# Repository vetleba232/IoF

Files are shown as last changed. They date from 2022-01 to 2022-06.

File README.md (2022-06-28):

# Realisation of an ultra-low power LPWAN embedded buoy controller

Altium Designer files for cSLIM-v1, a ultra low-power embedded buoy controller for the Internet of Fish project at NTNU.
The developed PCB design is a part of my specialization project-TTK4551. 

Vetle Berg Abrahamsen, January 2022

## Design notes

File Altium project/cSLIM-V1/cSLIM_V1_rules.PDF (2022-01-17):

## Report Generated From Altium Designer

Name | Priority | Enabled Type | Category | Scope | Attributes
ANT_clearence_polygon | 1 | True | Clearance | Electrical | InNet('nRF_GPS_LN
A') or
InNet('LTE_ANT') or
InNet('NetIC901_11')
orInNet('GPS_ANTE
NNA_nRF') orInNet('
GPS_ANTENNA_EX
T') - All

Generic clearance = 0.125mm, and 6 value(s) for objects

AssemblyTestpoint | 1 | True | Assembly Testpoint
| | | Style | Testpoint | All | Under Comp - Allow Sides - Top, Bottom Pref Size = 1.524mm Pref Hole Size
| | | | | | = 0.813mm Using Grid = Yes Grid = 0.025mm Grid Tolerance = 0mm
AssemblyTestPointUsage | 1 | True | Assembly Testpoint
| | | Usage | Testpoint | All | Testpoint - One Required Multiple - Not Allowed
ComponentClearance | 1 | True | Component Clearance Placement | All - All | Horizontal Clearance = 0.254mm Vertical Clearance = 0.254mm
DiffPairsRouting | 1 | True | Differential Pairs
| | | Routing | Routing | All | Pref Gap = 0.193mm Min Gap = 0.19mm Max Gap = 0.254mmPref Width =
| | | | | | 0.165mm Min Width = 0.165mm Max Width = 0.165mm
FabricationTestpoint | 1 | True | Fabrication Testpoint
| | | Style | Testpoint | All | Under Comp - Allow Sides - Top, Bottom Pref Size = 1.524mm Pref Hole Size
| | | | | | = 0.813mm Using Grid = Yes Grid = 0.025mm Grid Tolerance = 0mm
FabricationTestPointUsage | 1 | True | Fabrication Testpoint
| | | Usage | Testpoint | All | Testpoint - One Required Multiple - Not Allowed
Fanout_BGA | 1 | True | Fanout Control | Routing | IsBGA | Style - Auto Direction - Alternating In and Out Via Grid = 0.025mm
GND_STAR | 1 | False | Routing Topology | Routing | InNet('GND') | Topology - Starburst
Height | 1 | True | Height | Placement | All | Pref Height = 12.7mm Min Height = 0mm Max Height = 25.4mm
HoleSize | 1 | True | Hole Size | Manufacturing | All | Min = 0.2mm Max = 2.54mm
HoleToHoleClearance | 1 | True | Hole To Hole
| | | Clearance | Manufacturing | All - All | Hole To Hole Clearance = 0.279mm
LayerPairs | 1 | True | Layer Pairs | Manufacturing | All | Layer Pairs - Enforce
MinimumAnnularRing | 1 | True | Minimum Annular Ring Manufacturing | All | Min = 0.15mm
MinimumSolderMaskSliver | 1 | True | Minimum Solder Mask
| | | Sliver | Manufacturing | All - All | Minimum Solder Mask Sliver = 0.254mm
NetAntennae | 1 | True | Net Antennae | Manufacturing | All | Net Antennae Tolerance = 0mm
netties rule | 1 | True | Short-Circuit | Electrical | HasFootprint('NETTI
| | | | | E_FP') - All | Short Circuit - Allowed
PasteMaskExpansion | 1 | True | Paste Mask Expansion Mask | All | Expansion = 0mm
PlaneClearance | 1 | True | Power Plane ClearancePlane | All | Clearance = 0.508mm
PlaneConnect | 1 | True | Power Plane Connect
| | | Style | Plane | All | Style - Relief Connect Expansion = 0.508mm Width = 0.254mm Gap =
| | | | | | 0.254mm # Entries = 4
PolygonConnect_1 | 1 | True | Polygon Connect Style Plane | isVia and
| | | | | inNet('GND') or isVia
| | | | | and innet('VDD') orIn
| | | | | Component('IC1201')
| | | | | and InNet('GND') -
| | | | | All | Style - Direct Connect
RoutingCorners | 1 | True | Routing Corners | Routing | All | Style - 45 Degree Min Setback = 2.54mm Max Setback = 2.54mm
RoutingLayers | 1 | True | Routing Layers | Routing | All | TopLayer - Enabled MidLayer1 - DisabledMidLayer2 - Enabled BottomLayer -
| | | | | | Enabled
RoutingPriority | 1 | True | Routing Priority | Routing | All | Priority = 0
RoutingVias | 1 | True | Routing Via Style | Routing | All | Pref Size = 0.5mm Pref Hole Size = 0.25mm
SilkToSilkClearance | 1 | True | Silk To Silk Clearance Manufacturing | All - All | Silk to Silk Clearance = 0.254mm
SilkToSolderMaskClearance | 1 | True | Silk To Solder Mask
| | | Clearance | Manufacturing | IsPad - All | Silk To Solder Mask Clearance = 0.254mm
SMDNeckDown | 1 | True | SMD Neck-Down | SMT | All | Percent = 80%
SolderMaskExpansion_VIA | 1 | True | Solder Mask Expansion Mask | IsVia | Expansion = 0.102mm
UnpouredPolygon | 1 | True | Modified Polygon | Electrical | All | Allow modified - No Allow shelved - No
UnRoutedNet | 1 | True | Un-Routed Net | Electrical | All | (No Attributes)
Width_PWR | 1 | True | Width | Routing | InNetClass('PWR') | Pref Width = 0.4mm Min Width = 0.15mm Max Width = 0.4mm
onsdag 12-jan-12.2022 12:27:38 PM | | | | | | Page 1 of 2

Name | Priority | Enabled Type | Category | Scope | Attributes
Fanout_LCC | 2 | True | Fanout Control | Routing | IsLCC | Style - Auto Direction - Alternating In and Out Via Grid = 0.025mm
PolygonConnect | 2 | True | Polygon Connect Style Plane | All - All | Style - Relief Connect Width = 0.254mm Angle = 90 # Entries = 4 Air Gap =
| | | | | | 0.254mm
RoutingTopology | 2 | True | Routing Topology | Routing | All | Topology - Shortest
ShortCircuit | 2 | True | Short-Circuit | Electrical | All - All | Short Circuit - Not Allowed
SolderMaskExpansion | 2 | True | Solder Mask Expansion Mask | All | Expansion = 0.102mm
USB_polygon | 2 | True | Clearance | Electrical | InNamedPolygon('L1-
| | | | | GND-Polygon') -
| | | | | (IsTrack or IsArc) and
| | | | | (InDifferentialPair('D')
| | | | | orInDifferentialPair('U
| | | | | SB0')) | Clearance = 1.397mm
Width_diff | 2 | True | Width | Routing | (InDifferentialPairClas
| | | | | s('All Differential
| | | | | Pairs')) | Pref Width = 0.165mm Min Width = 0.165mm Max Width = 0.165mm
Fanout_SOIC | 3 | True | Fanout Control | Routing | IsSOIC | Style - Auto Direction - Alternating In and Out Via Grid = 0.025mm
USB_clearence | 3 | True | Clearance | Electrical | (InDifferentialPairClas
| | | | | s('All Differential
| | | | | Pairs')) - All | Generic clearance = 0.152mm, and 9 value(s) for objects
Width_GPIO_1 | 3 | True | Width | Routing | InNetClass('GPIO') or
| | | | | InNetClass('COEX')
| | | | | or InNetClass('SWD')
| | | | | or
| | | | | InNetClass('UART') | Pref Width = 0.15mm Min Width = 0.15mm Max Width = 0.152mm
Fanout_Small | 4 | True | Fanout Control | Routing | (CompPinCount < 5) Style - Auto Direction - Out Then In Via Grid = 0.025mm
nRFfootprint | 4 | True | Clearance | Electrical | HasFootprint('XCVR_
| | | | | NRF9160-SICA-R7')
- All
| | | | | | Clearance = 0.125mm
Width | 4 | True | Width | Routing | All | Pref Width = 0.15mm Min Width = 0.15mm Max Width = 0.254mm
Fanout_Default | 5 | True | Fanout Control | Routing | All | Style - Auto Direction - Alternating In and Out Via Grid = 0.025mm
Polygon_Clearence | 5 | True | Clearance | Electrical | (InNamedPolygon('L1
| | | | | -GND-Polygon')) or(In
| | | | | NamedPolygon('L4-G
| | | | | ND-Polygon')) or(InN
| | | | | amedPolygon('L2-GN
| | | | | D_polygon')) or(InNa
| | | | | medPolygon('L3-GND
| | | | | -Polygon')) - All | Generic clearance = 0.254mm, and 9 value(s) for objects
Top_layer_Clearance | 6 | True | Clearance | Electrical | All - OnLayer('Top Layer') | Clearance = 0.125mm
Clearance | 7 | True | Clearance | Electrical | All - All | Clearance = 0.125mm
onsdag 12-jan-12.2022 12:27:38 PM | Page 2 of 2

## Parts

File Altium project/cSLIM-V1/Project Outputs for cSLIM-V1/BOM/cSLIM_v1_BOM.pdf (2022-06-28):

Designator | Value | Quantity | Manufacturer_Part_Number | Description
A1 | | 1 | P822601 | CDMA, DCS, EDGE, GPRS, GSM, HSDPA, LTE, PCS, UMTS, WCDMA Flat Bar RF Antenna
C301, C401, C402, C403, C404, C405, C601, C604, C606, C806, C810, C901, C904, C905, C907, C1001, C1202, C1205, C1209, C1215 | 100nF | 20 | CL10B104KB8NNNL | Capacitor
C501 | 12pF | 1 | 0603N120J500CT | Capacitor
C502 | 10nF | 1 | CL10B103KB8NNNC | Capacitor
C602, C603, C902, C1216, C1217 | 1uF | 5 | CL10A105KO8NNNC | Capacitor
C605 | 10uF | 1 | CL10X106MP8NRNC | Capacitor
C607 | 22uF | 1 | CL10A226KQ8NRNE | Capacitor
C608 | 1.8pF | 1 | CL10C1R8BB8NNNC | Capacitor
C609 | | 1 | PCH1E101MCL4GS | Alum.Organic Polymer Capacitors 100UF 25V ESR=27
C807 | 1uF/50V | 1 | CL10A105KB8NNNC | Capacitor
C903, C906 | 100pF | 2 | CL10C101JB8NNNC | Capacitor
C1201, C1208 | 15pF | 2 | CL10C150JB81PNC | Capacitor
C1203, C1210 | 47uF | 2 | GRM188D70E476ME01D | Capacitor
C1206, C1207 | 4.7uF | 2 | CL10A475KQ8NNNC | Capacitor
C1211 | 3.5pF | 1 | CL10C3R3CB81PNC | Capacitor
C1212, C1213, C1214 | N.C. | 3 | | Capacitor
D601 | | 1 | 1SS390SMFHT2R | RF Diode PIN - Single 35V 100 mA EMD2
D1201 | | 1 | CM1402-03CP | FILTER RC(PI) ESD SMD
FB501 | 500 mA, 600 Ohms | 1 | BLM18EG601SZ1D | Ferrite bead
FB801, FB802 | 60 OHM | 2 | 742792602 | Ferrite bead, [NoValue]
FB1201 | 120ohm 0.7A | 1 | BLM18AG121SH1D | Ferrite bead - 120ohm 0.7A
IC201 | | 1 | WLR089U0-I/RM | LONG RANGE LORA MODULE (863-928
IC202, IC701, IC902 | | 3 | SN74AVC4T774PWR | Logic Level Converter (LLC)
IC203, IC702, IC903 | | 3 | NX2301P,215 | P-Channel 20V 2A (Ta) 400mW (Ta), 2.8W (Tc) Surface Mount TO-236AB
IC301 | | 1 | MAX3486ESA+ | 1/1 Transceiver Half RS422, RS485 8-SOIC
IC302 | | 1 | MAX3471EUA+ | 1/1 Transceiver Half RS485 8-uMAX-EP|8-uSOP-EP
IC401 | | 1 | MAX3221CUE+ | 1/1 Transceiver Full RS232 16-TSSOP
IC601 | | 1 | TPS2113PWR | OR Controller Source Selector Switch N-Channel 2:1
IC901 | | 1 | NEO-M8N-0-10 | NEO-M9N-00B should be used if available
IC904 | | 1 | SKY65943-11 | GPS LNA MODULE
IC1001 | | 1 | CY15B108QN-20LPXC | IC FRAM 8MBIT SPI 20MHZ 8GQFN
IC1201 | | 1 | NRF9160-SICA-B1A-R7 | IC RF TxRx + MCU Cellular GPS 700MHz ~ 2.2GHz 161-TFLGA Module
IC1202 | | 1 | PCAL6408APWJ | I/O Expander 8 I2C, SMBus 400 kHz 16-TSSOP
J301, J302 | | 2 | 61300211121 | CONN HEADER VERT 2POS 2.54MM
J501 | | 1 | 70543-0001 | BAT CONN HEADER VERT 2POS 2.54MM
J502 | | 1 | PH1-04-UA | CONN HEADER VERT 4POS 2.54MM
J503 | | 1 | 61300611121 | CONN HEADER VERT 6POS 2.54MM
J504 | | 1 | 10119313-302TLF | USB - mini B USB 2.0 Receptacle Connector 5 Position Through Hole
J505, J515 | | 2 | 61300311121 | CONN HEADER VERT 3POS 2.54MM
J506 | | 1 | 104031-0811 | CONN MICRO SD CARD PUSH-PULL R/A
J507, J514 | | 2 | CONUFL001-SMD-T | CONN UMC JACK STR SMD
J508, J512 | | 2 | SHF-105-01-L-D-SM-LC-K-TR | CONN HEADER SMD 10POS 1.27MM
J509, J510 | | 2 | BM05B-ZESS-TBT (LF)(SN) | RS232/RS485 CONN HEADER SMD 5POS 1.5MM
J513 | | 1 | SF72S006VBAR2500 | NANO SIM CARD PUSH-PUSH
J516 | | 1 | TSW-103-08-S-D | Auxillary 2x3 conn
J802 | | 1 | 52746-1071 | LCD connector CONN FFC BOTTOM 10POS 0.50MM R/A
L601 | | 1 | LPS3015-222MRB | Inductor
L901 | 27nH | 1 | LQG18HH27NJ00D | Inductor
L902 | 9n1 | 1 | LQW18AN9N1D00D | Inductor
L1201 | 22nH | 1 | LQW18AN22NJ00D | Inductor
L1202 | 1.5nH | 1 | LQG18HN1N5S00D | Inductor
LED501 | | 1 | APT2012LSECK/J3-PRV | LED RED CLEAR 2SMD
LED502 | | 1 | APT2012LSYCK/J3-PRV | LED YELLOW CLEAR 2SMD
LED503 | | 1 | APT2012LZGCK | LED GREEN CLEAR 2SMD
LED504, LED505 | | 2 | APT2012LVBC/D | LED BLUE CLEAR 2SMD
PB1201, PB1202, S601 | | 3 | TLS A 070J LFS | SWITCH TACTILE SPST-NO 0.05A 12V
Q901 | | 1 | SI1040X-T1-GE3 | IC PWR SWITCH P-CHAN 1:1 SC89-6
R201, R202, R203, R603, R701, R702, R703, R801, R804, R901, R902, R903, R906, R1102, R1103, R1209, R1210, R1211, R1212, R1213 | 100k | 20 | RC0603FR-07100KL | Resistor
R301 | 120R | 1 | RT0603DRD07120RL | Resistor
R302, R303 | 680R | 2 | RC0603JR-07680RL | Resistor
R501, R502 | 15R | 2 | RC0603JR-0715RL | Resistor
R503, R508, R509, R511, R904, R907, R908, R1204, R1205, R1206, R1216, R1217 | 0R | 12 | YJP1608-R001 | Resistor
R504, R505 | 820R | 2 | RC0603FR-07820RL | Resistor
R506, R507, R510 | 330R | 3 | RC0603FR-07330RL | Resistor
R601, R609 | 240k | 2 | RC0603FR-07240KL | Resistor
R602, R606, R909 | 1M | 3 | RC0603FR-131ML | Resistor
R604 | 390R | 1 | RC0603JR-07390RL | Resistor
R605, R1214, R1215 | 1k | 3 | RC0603FR-071KL | Resistor
R607 | 100R | 1 | RC0603FR-07100RL | Resistor
R608 | 1M2 | 1 | RC0603FR-071M2L | Resistor
R610 | 3k | 1 | RC0603FR-073KL | Resistor
R905 | 10R | 1 | RC0603FR-1310RL | Resistor
R1001, R1002 | 33R | 2 | RC0603FR-0733RL | Resistor
R1003 | 50R | 1 | RC0603FR-0749R9L | Resistor
R1101, R1201 | 10k | 2 | RC0603FR-0710KL | Resistor
R1202, R1203 | 4.7k | 2 | RC0603FR-074K7L | Resistor
S201 | | 1 | 97C08ST | 8-Pin address switch
U501 | | 1 | USBLC6-2SC6 | 17V Clamp 5A (8/20µs) Ipp Tvs Diode SMD
U601 | | 1 | TPS63000DRCR | Buck-Boost Switching Regulator IC Positive Adjustable 1.2V 1 Output 1.6A (Switch) 10-VFDFN Exposed Pad
Y1101 | | 1 | RV-3032-C7-TA-QC | Real Time Clock Serial I2C 16Bytes 8-Pin SON T/R
Display | 1 | LS013B7DH03 | LCD TFT 1.28" 128X128 FPC
Jumper | 3 | SPC02SXIN-RC | CONN JUMPER SHORTING .100" GOLD
GNSS antenna | 1 (2) | FXP611.07.0092C | RF ANT 1.6GHZ FLAT PATCH IPEX. (Internal or external)
cSLIM-v1 PCB + stencil | 1 | W485774ASF10 | Prod.num can be used to repeat order: stock 9 PCB
SWD cable | 1 | 1528-2009-ND | 10-PIN 2X5 SOCKET-SOCKET 1.27MM
USB cable | 1 | Not specified | USB 2.0 to USB MINI for power.
SEGGER programmer | 1 | Not specified | SWD prog and RTT view. SEGGER EDU or nRF9160 DK.

Components not specified in the generated BOM

Required accessories

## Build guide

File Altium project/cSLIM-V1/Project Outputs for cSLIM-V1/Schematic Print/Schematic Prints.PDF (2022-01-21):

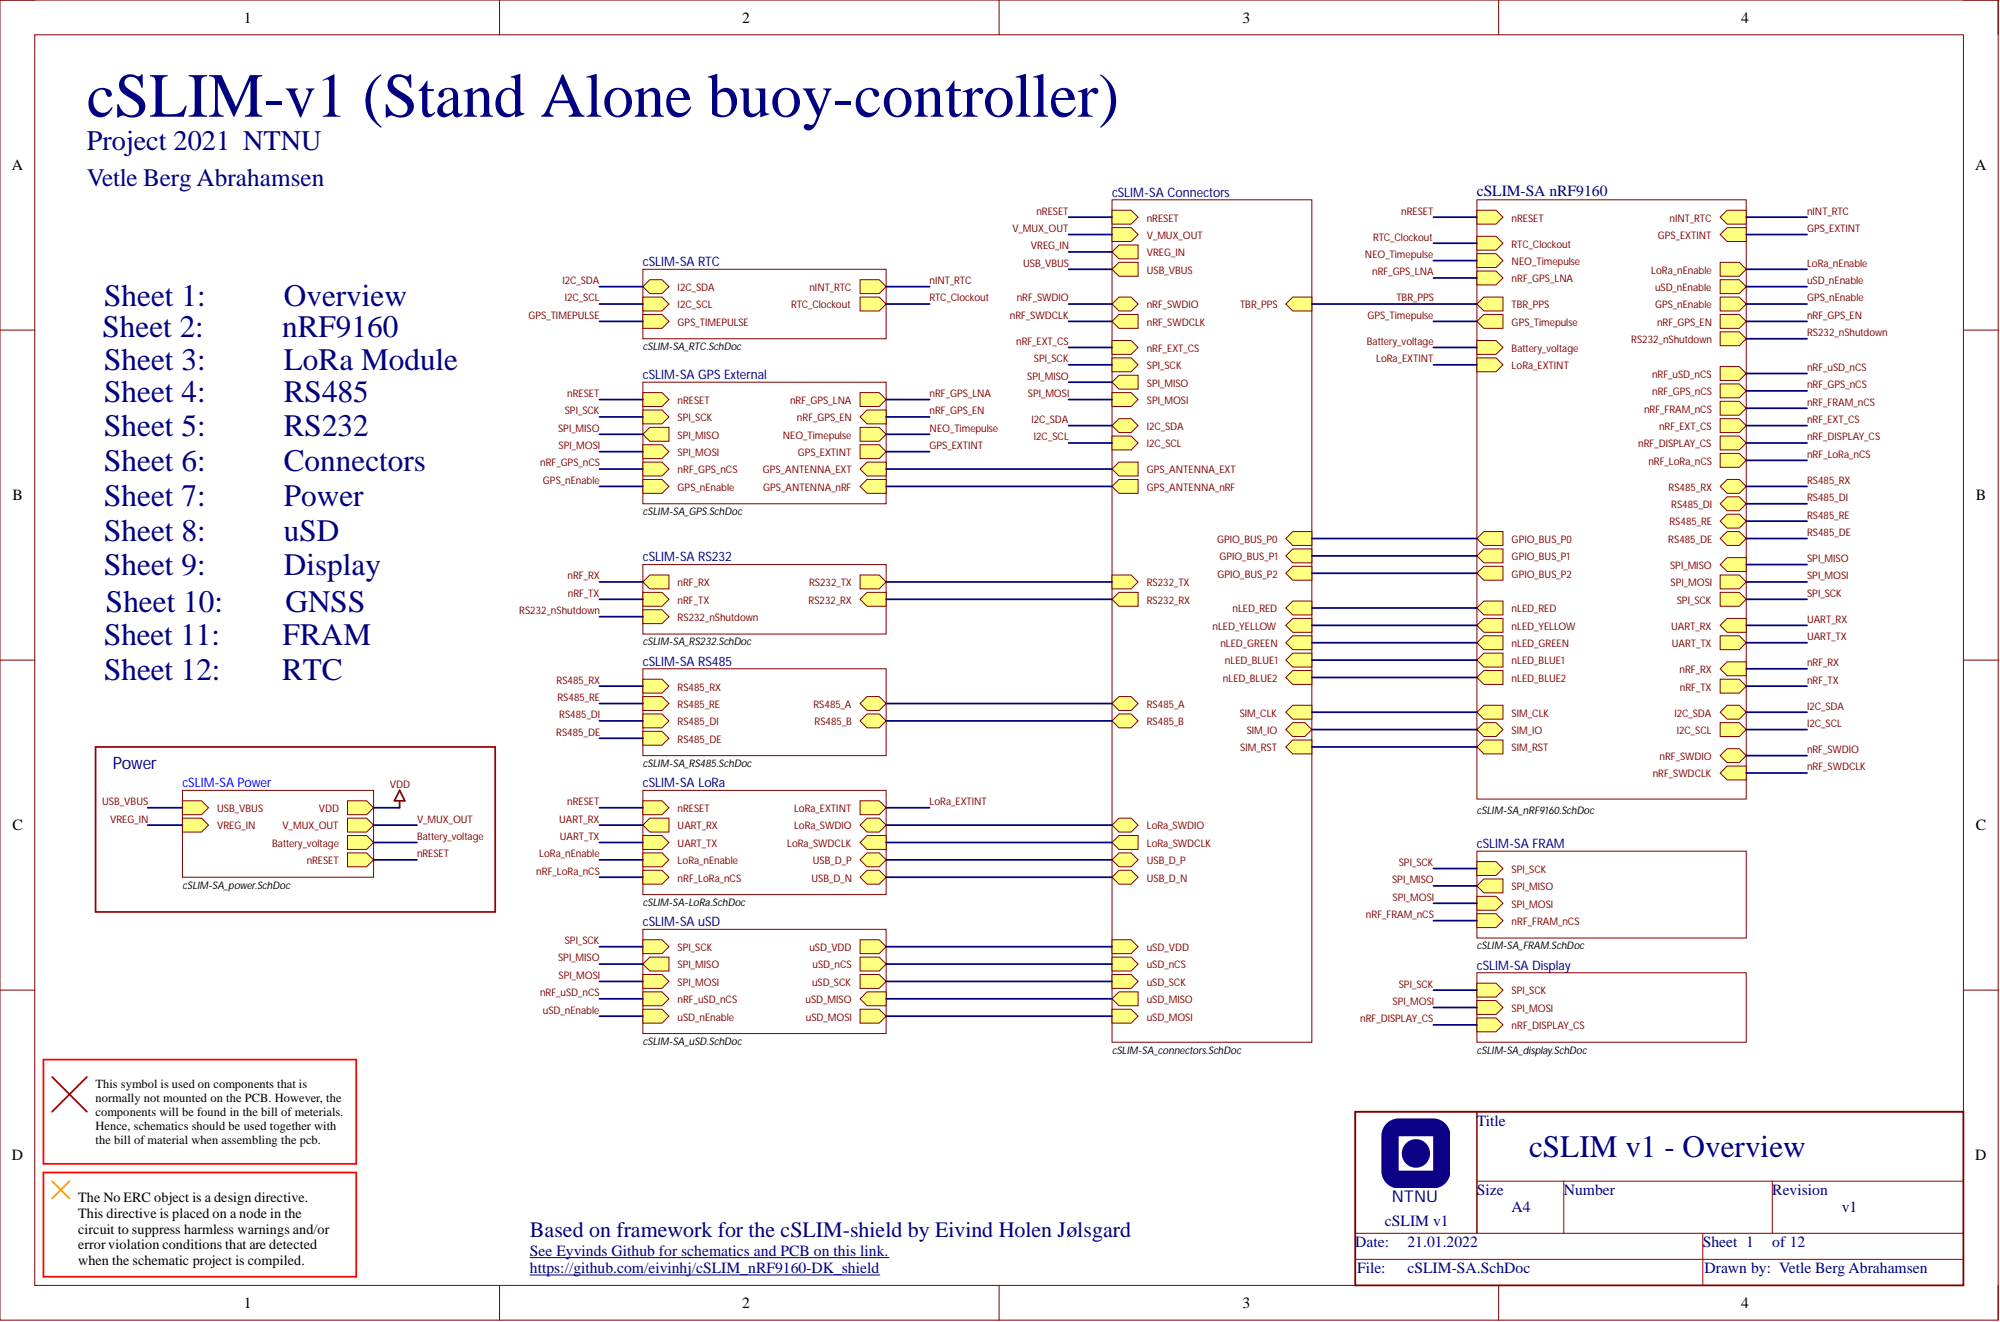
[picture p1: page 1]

cSLIM-v1 (Stand Alone buoy-controller)

cSLIM-SA GPS External

cSLIM-SA-LoRa.SchDoc
cSLIM-SA uSD

This symbol is used on components that is
normally not mounted on the PCB. However, the
components will be found in the bill of meterials.
Hence, schematics should be used together with
the bill of material when assembling the pcb.

NTNU cSLIM v1 | Title cSLIM v1 - Overview

Size A4 | Number | Revision v1

The No ERC object is a design directive.
This directive is placed on a node in the
circuit to suppress harmless warnings and/or
error violation conditions that are detected
when the schematic project is compiled.

Based on framework for the cSLIM-shield by Eivind Holen Jølsgard
See Eyvinds Github for schematics and PCB on this link. (https://github.com/eivinhj/cSLIM_nRF9160-DK_shield)
https://github.com/eivinhj/cSLIM_nRF9160-DK_shield

Date: 21.01.2022 | Sheet of
File: cSLIM-SA.SchDoc | Drawn by: Vetle Berg Abrahamsen

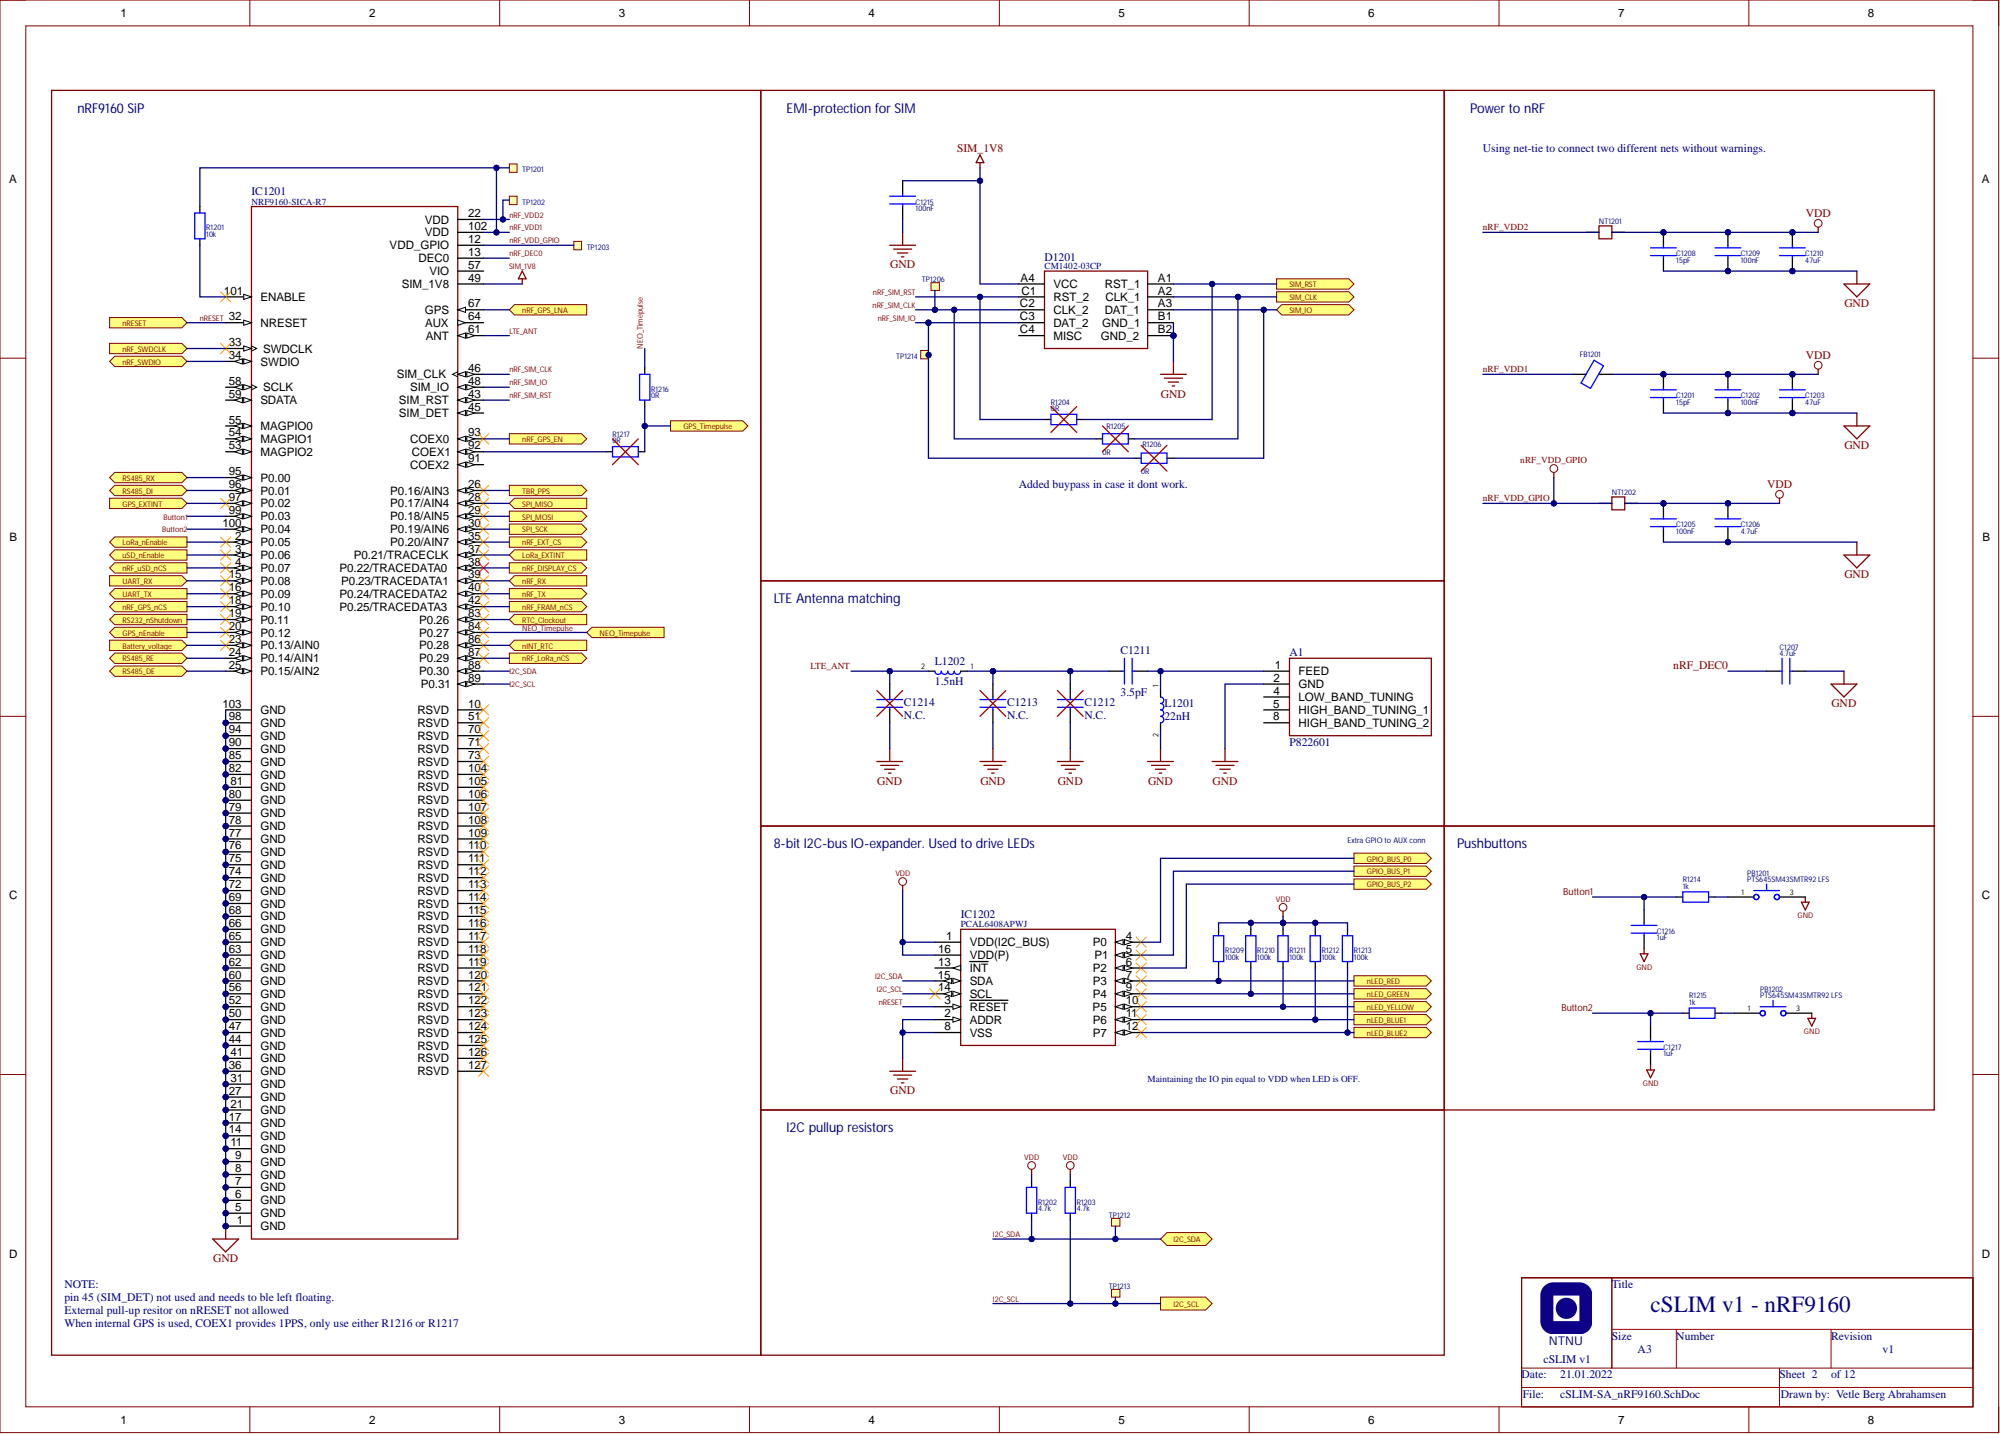
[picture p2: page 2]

EMI-protection for SIM

Using net-tie to connect two different nets without warnings.

MISC C4

Added buypass in case it dont work.

8-bit I2C-bus IO-expander. Used to drive LEDs

Extra GPIO to AUX conn

Maintaining the IO pin equal to VDD when LED is OFF.

NOTE:
pin 45 (SIM_DET) not used and needs to ble left floating.
External pull-up resitor on nRESET not allowed
When internal GPS is used, COEX1 provides 1PPS, only use either R1216 or R1217

NTNU | Title cSLIM v1 - nRF9160

Size A3 | Number | Revision v1

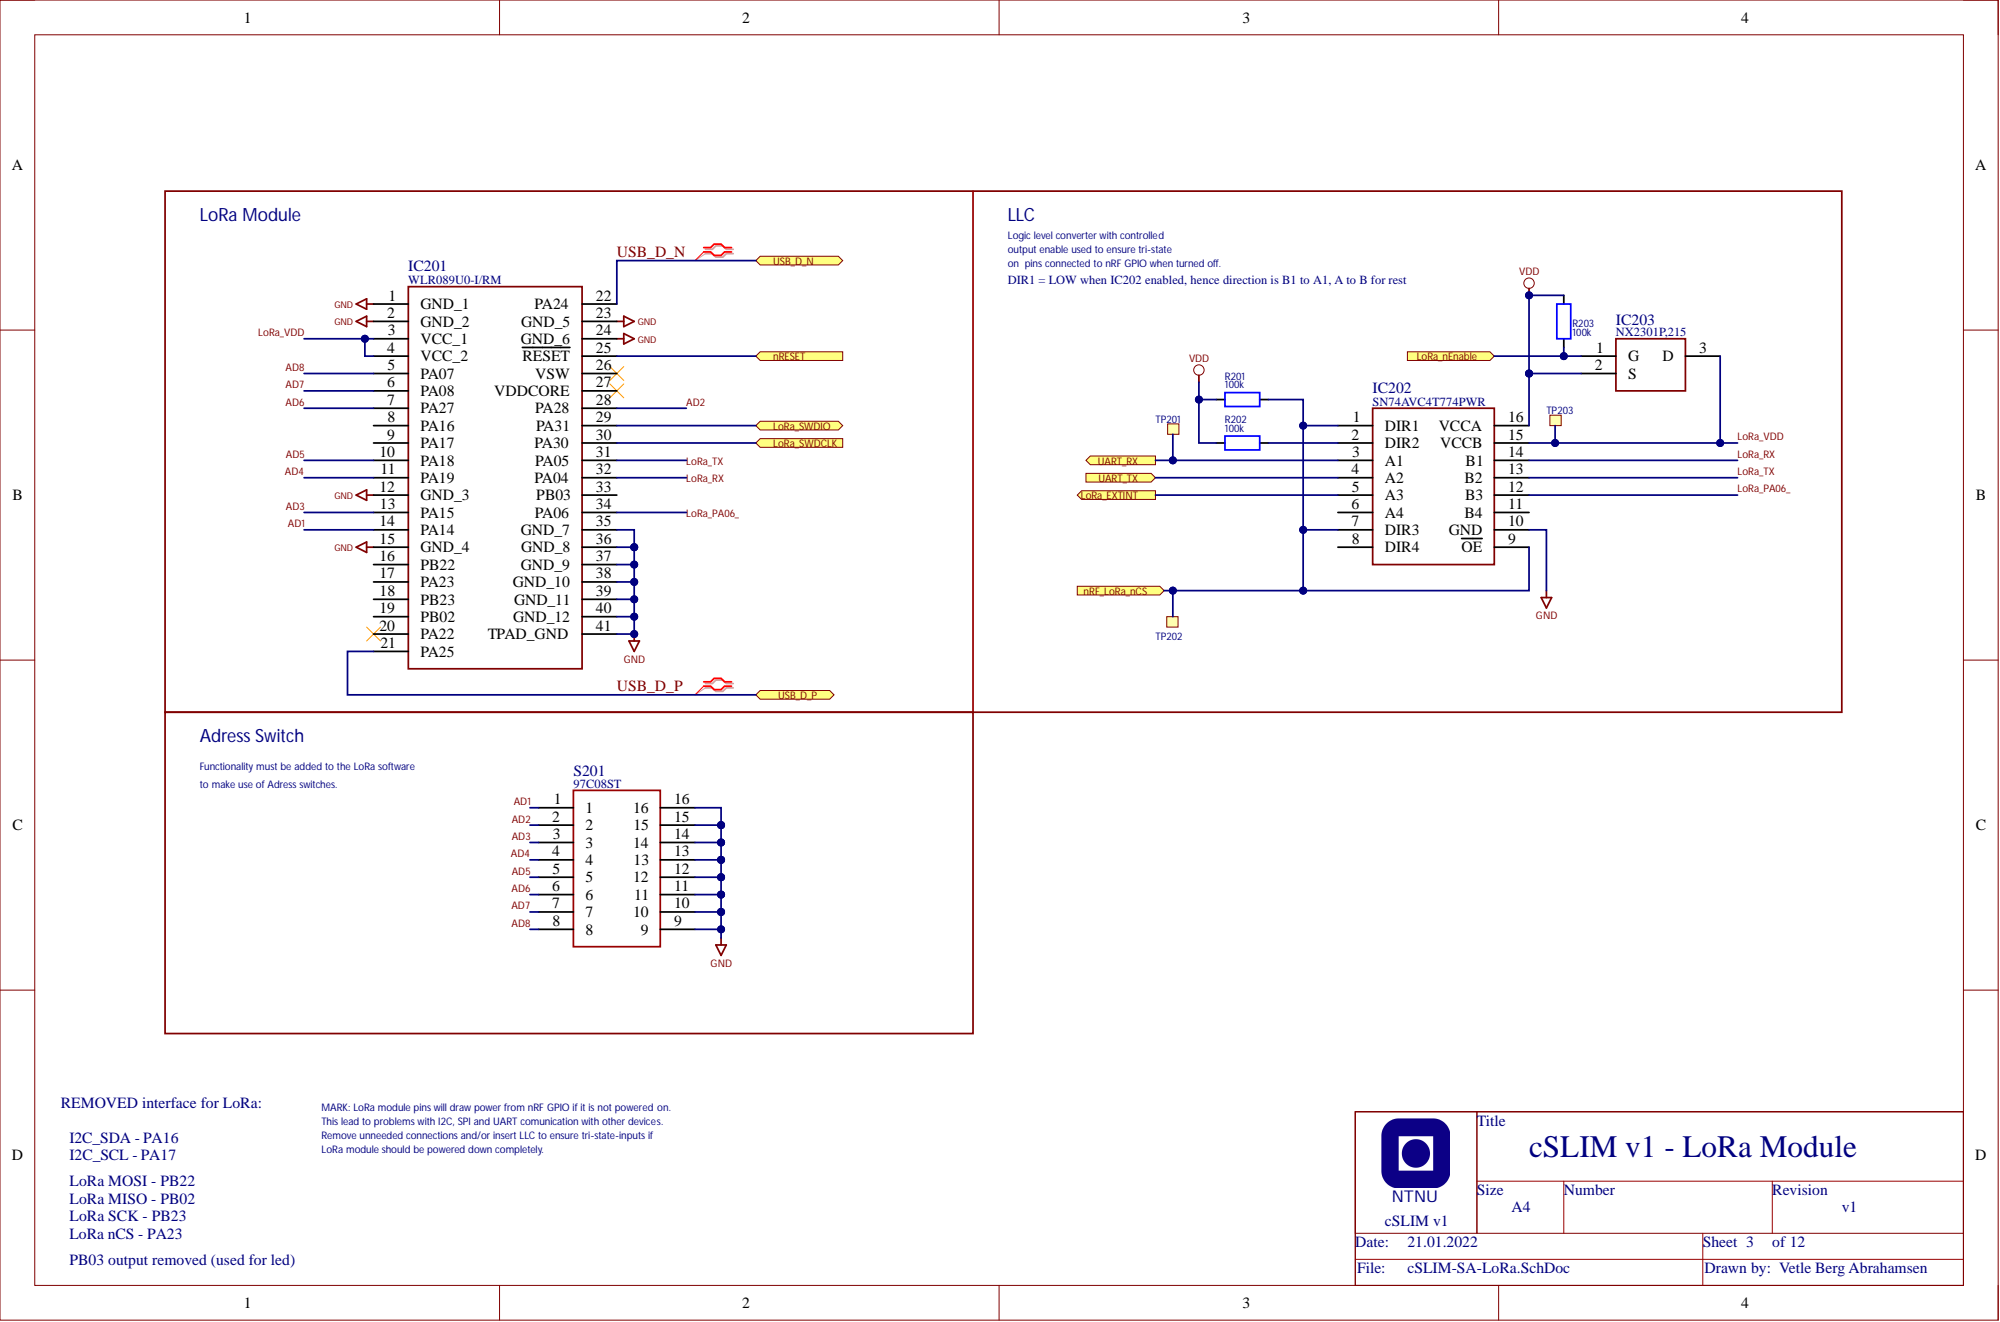
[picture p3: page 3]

output enable used to ensure tri-state
on pins connected to nRF GPIO when turned off.
DIR1 = LOW when IC202 enabled, hence direction is B1 to A1, A to B for rest

Functionality must be added to the LoRa software
to make use of Adress switches.

REMOVED interface for LoRa:

MARK: LoRa module pins will draw power from nRF GPIO if it is not powered on.
This lead to problems with I2C, SPI and UART comunication with other devices.
Remove unneeded connections and/or insert LLC to ensure tri-state-inputs if
LoRa module should be powered down completely.

NTNU | Title cSLIM v1 - LoRa Module

Size A4 | Number | Revision v1

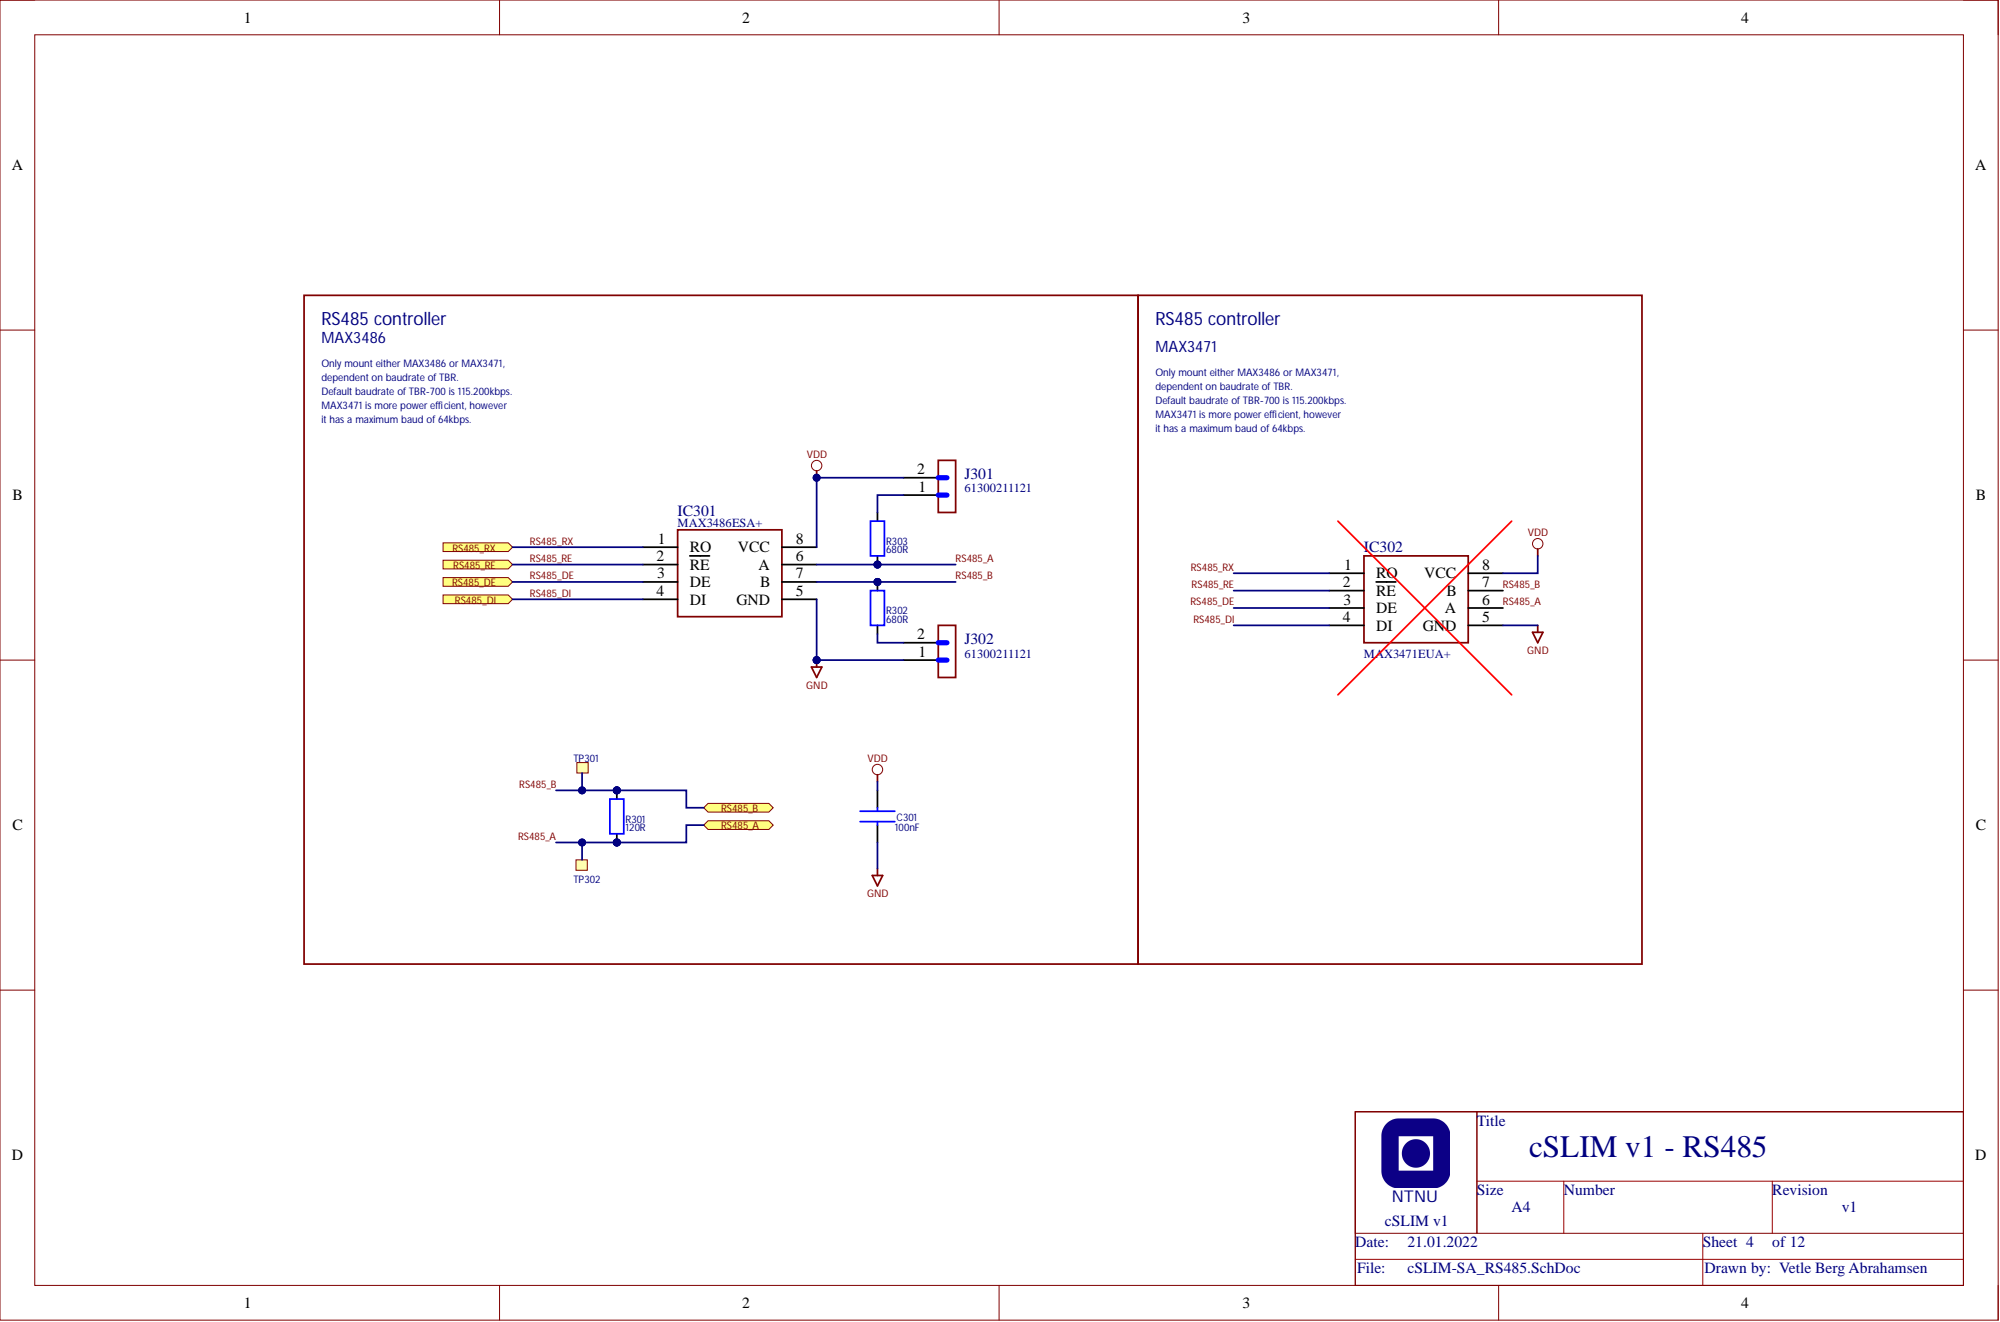
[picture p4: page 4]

Only mount either MAX3486 or MAX3471,
dependent on baudrate of TBR.
Default baudrate of TBR-700 is 115.200kbps.
MAX3471 is more power efficient, however
it has a maximum baud of 64kbps.

VDD | VDD IC302

NTNU | Title cSLIM v1 - RS485

Size A4 | Number | Revision v1

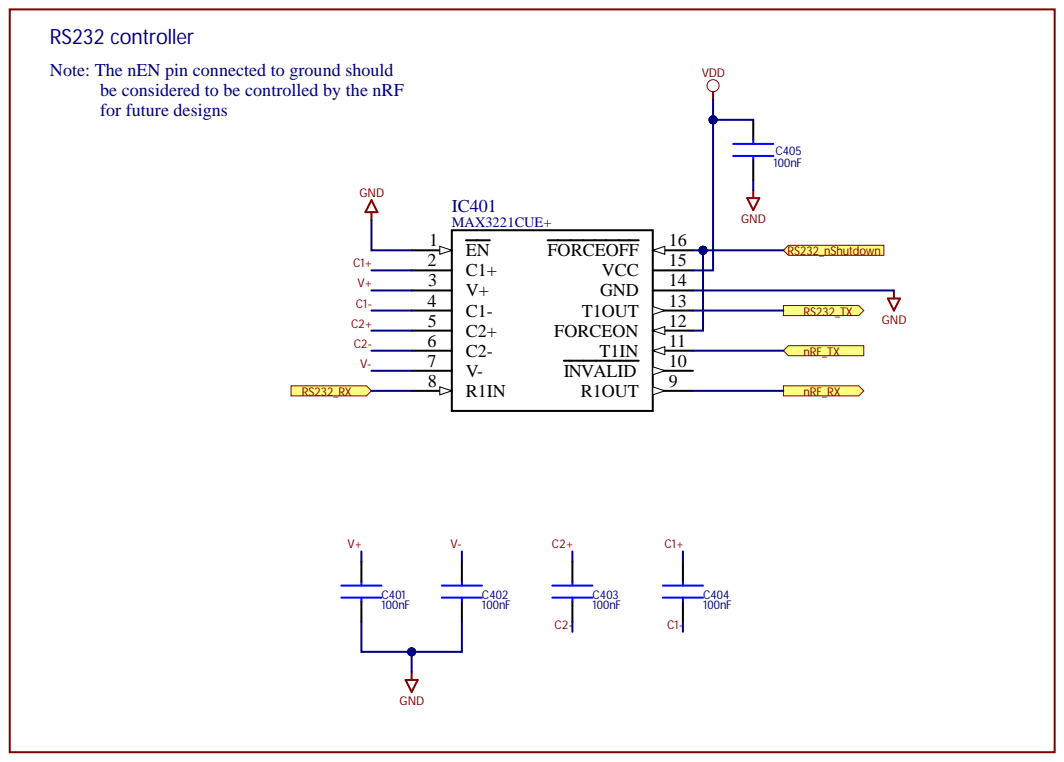
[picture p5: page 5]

Note: The nEN pin connected to ground should
be considered to be controlled by the nRF
for future designs

NTNU | Title cSLIM v1 - RS232

Size A4 | Number | Revision v1

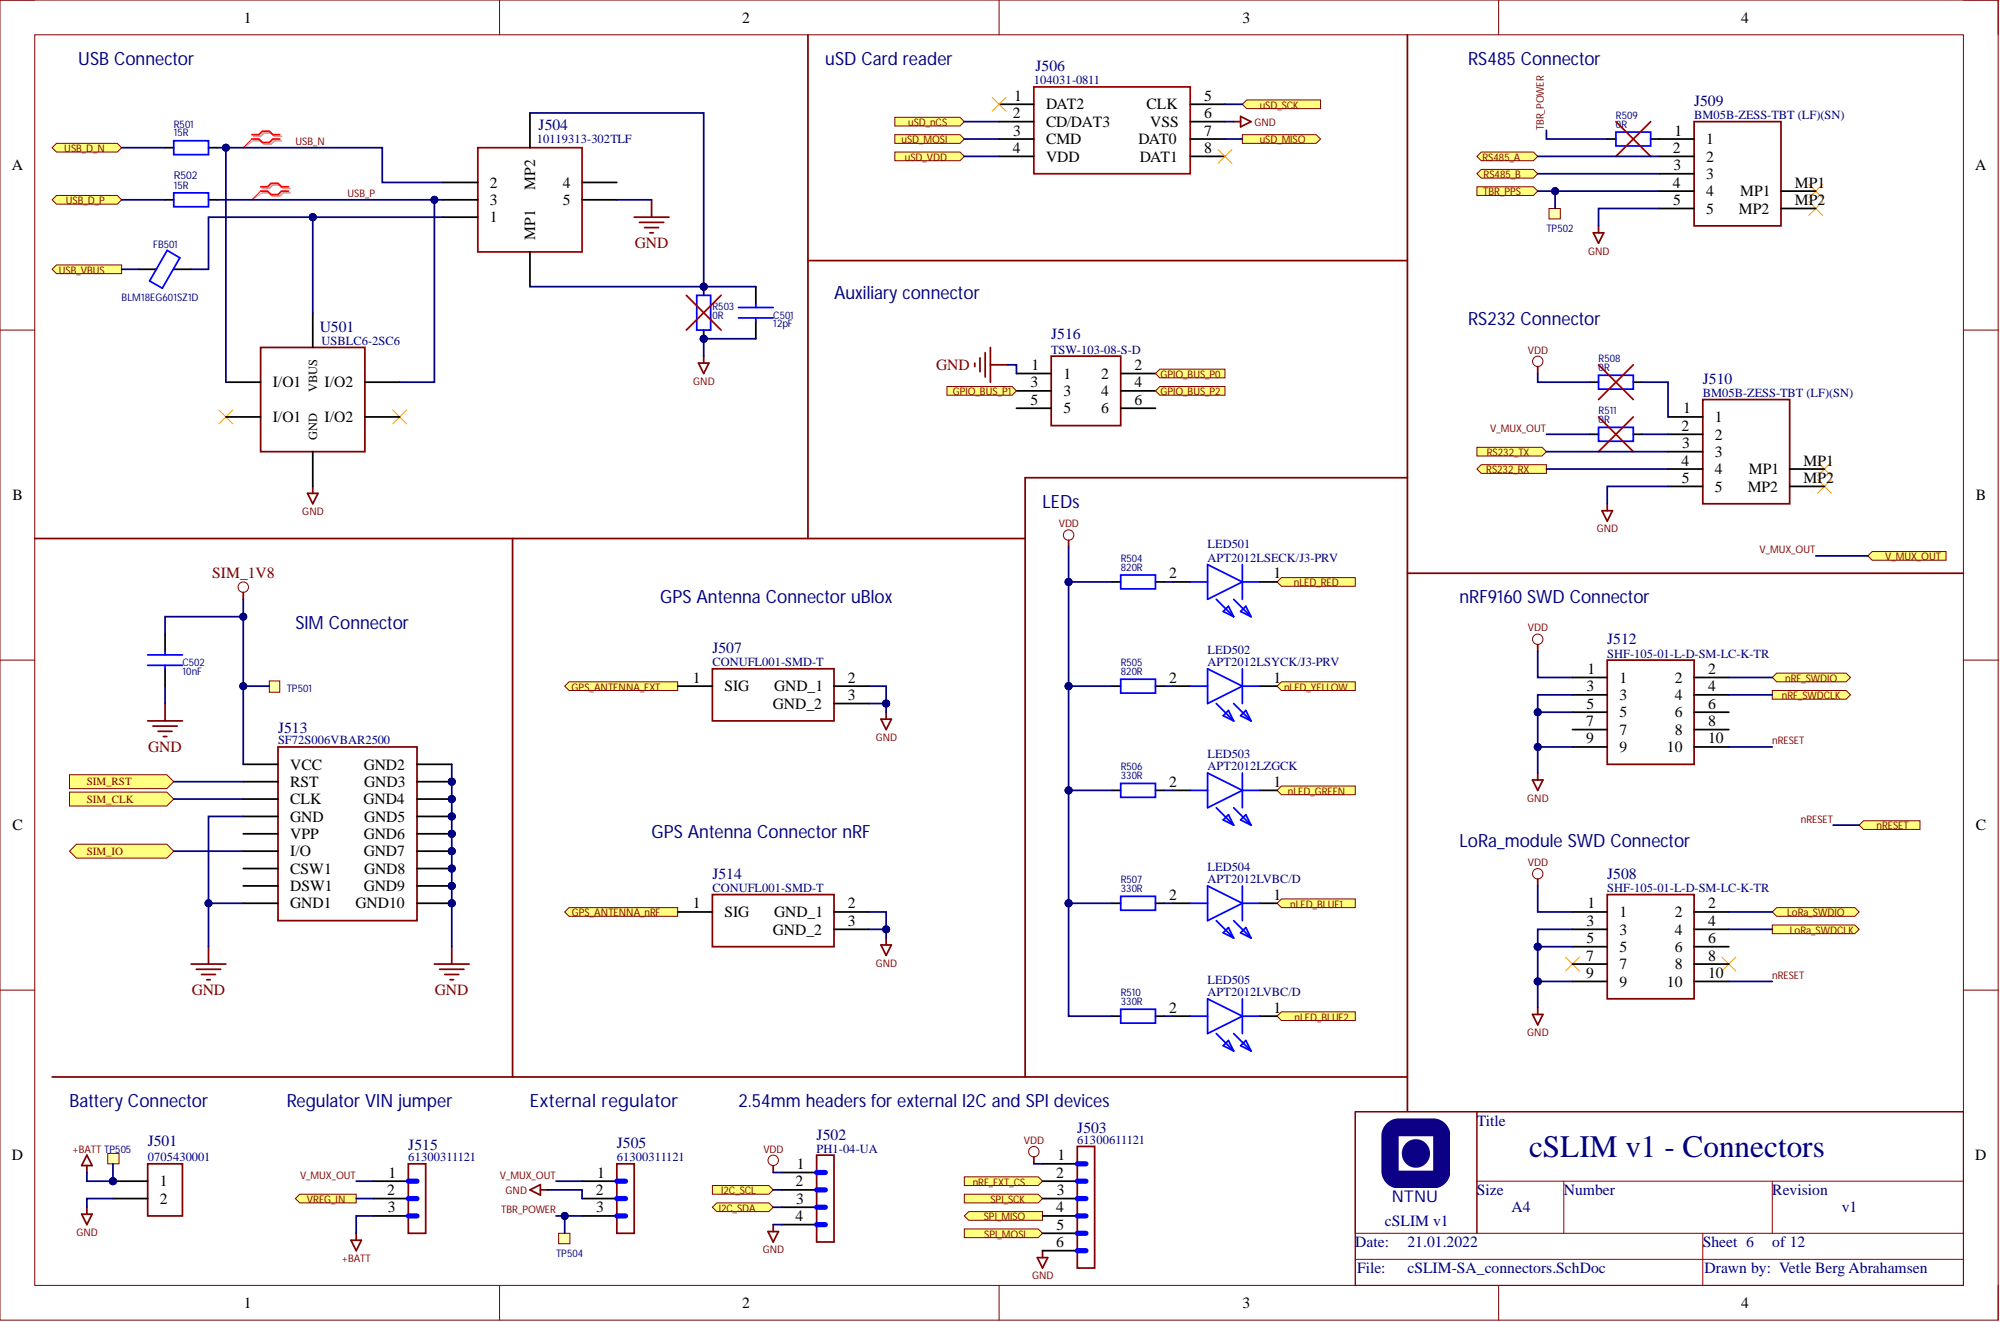
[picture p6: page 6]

GPS Antenna Connector uBlox

SHF-105-01-L-D-SM-LC-K-TR

GPS Antenna Connector nRF

2.54mm headers for external I2C and SPI devices

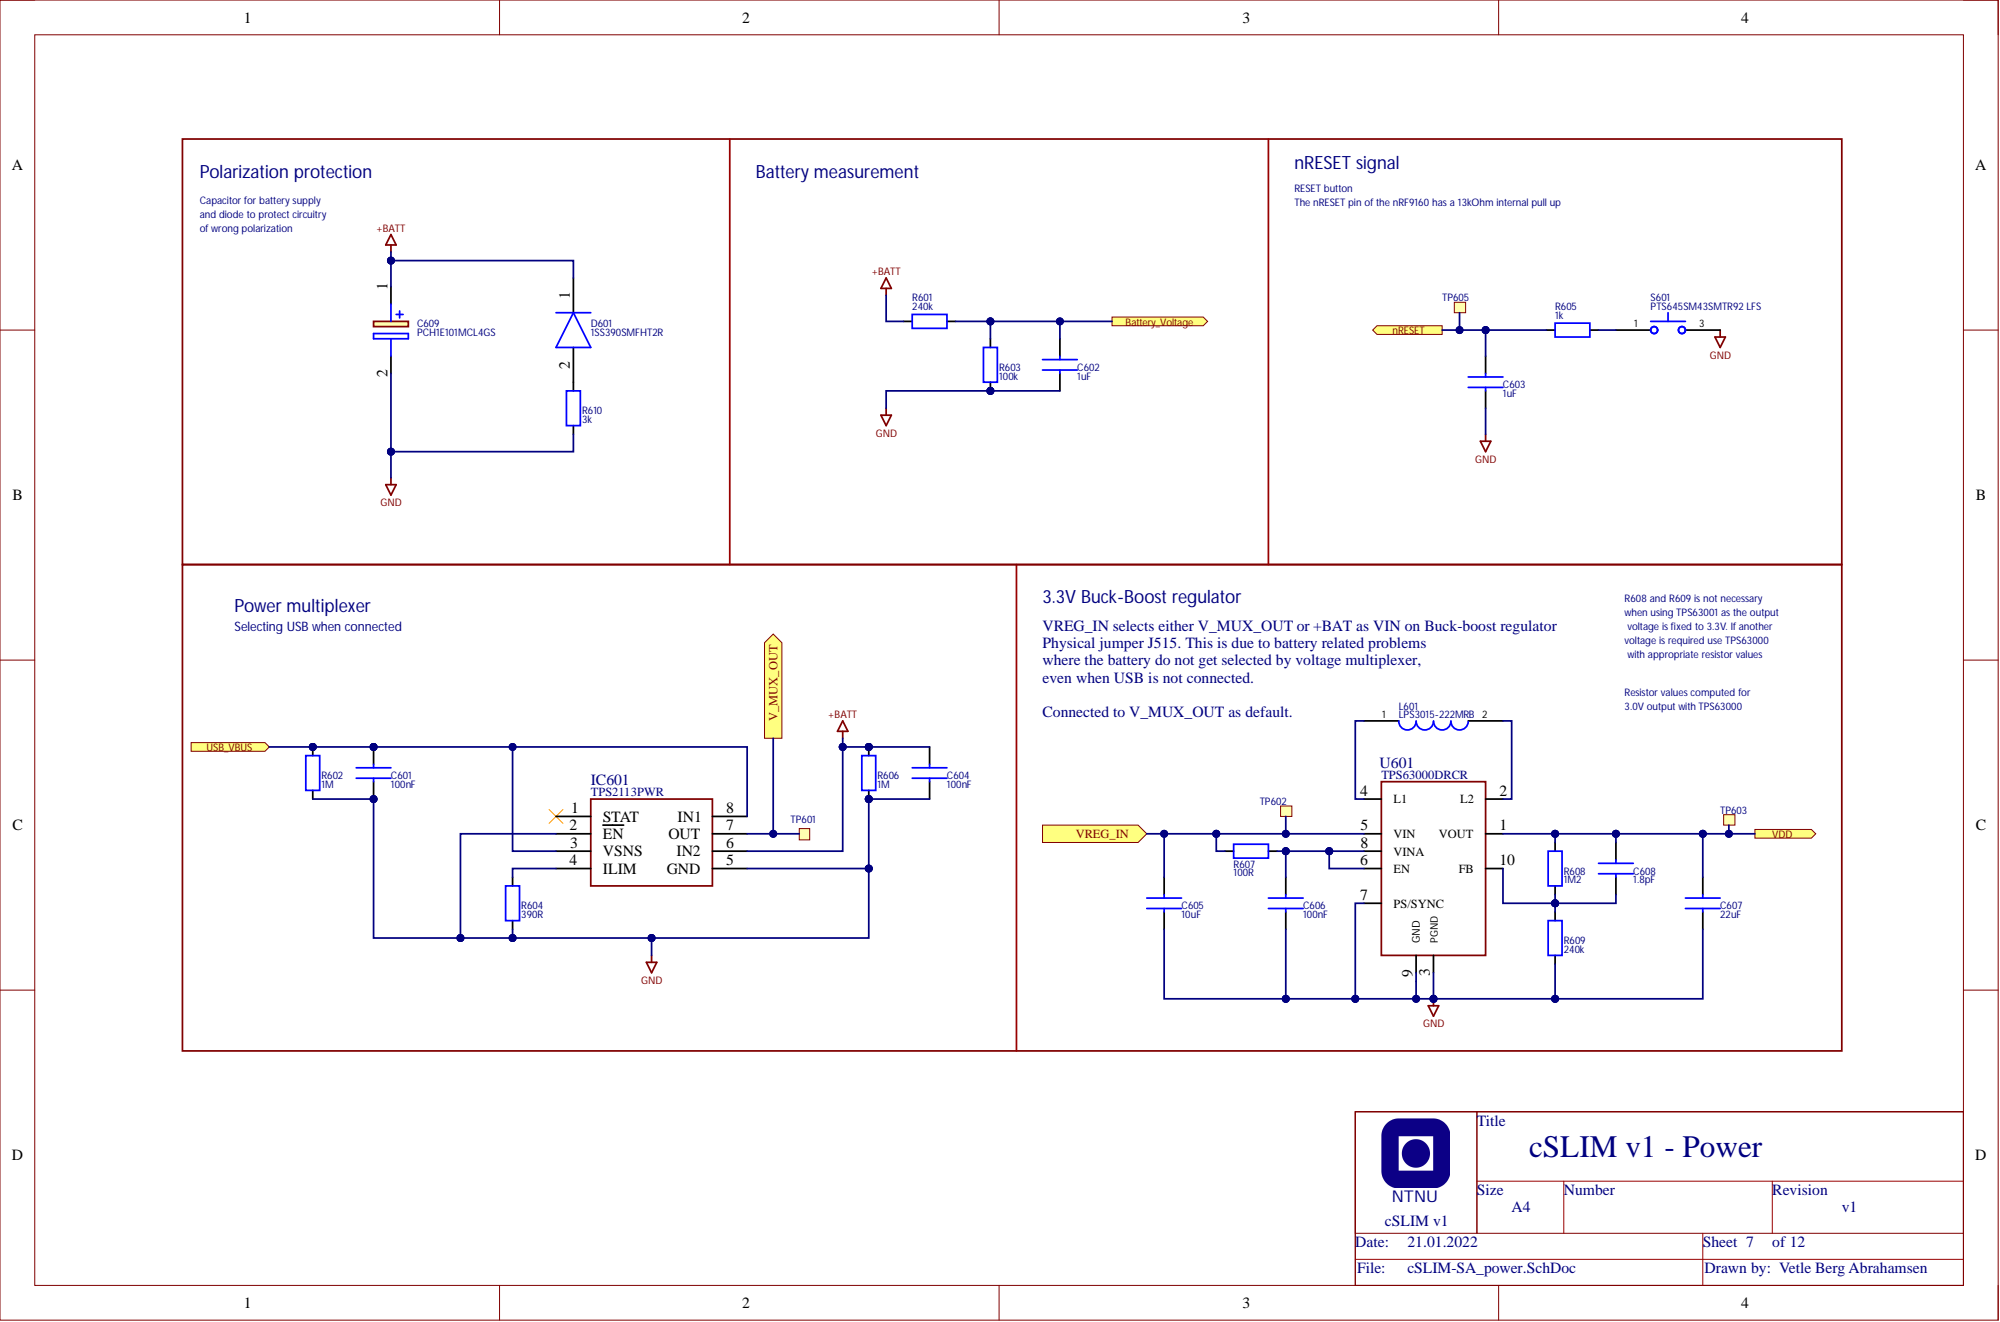
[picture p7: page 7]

Capacitor for battery supply
and diode to protect circuitry
of wrong polarization

RESET button
The nRESET pin of the nRF9160 has a 13kOhm internal pull up

R608 and R609 is not necessary
when using TPS63001 as the output
voltage is fixed to 3.3V. If another
voltage is required use TPS63000
with appropriate resistor values

Selecting USB when connected

VREG_IN selects either V_MUX_OUT or +BAT as VIN on Buck-boost regulator
Physical jumper J515. This is due to battery related problems
where the battery do not get selected by voltage multiplexer,
even when USB is not connected.

Resistor values computed for
3.0V output with TPS63000

Connected to V_MUX_OUT as default.

EN 2 OUT | 7

ILIM 4

NTNU | Title cSLIM v1 - Power

Size A4 | Number | Revision v1

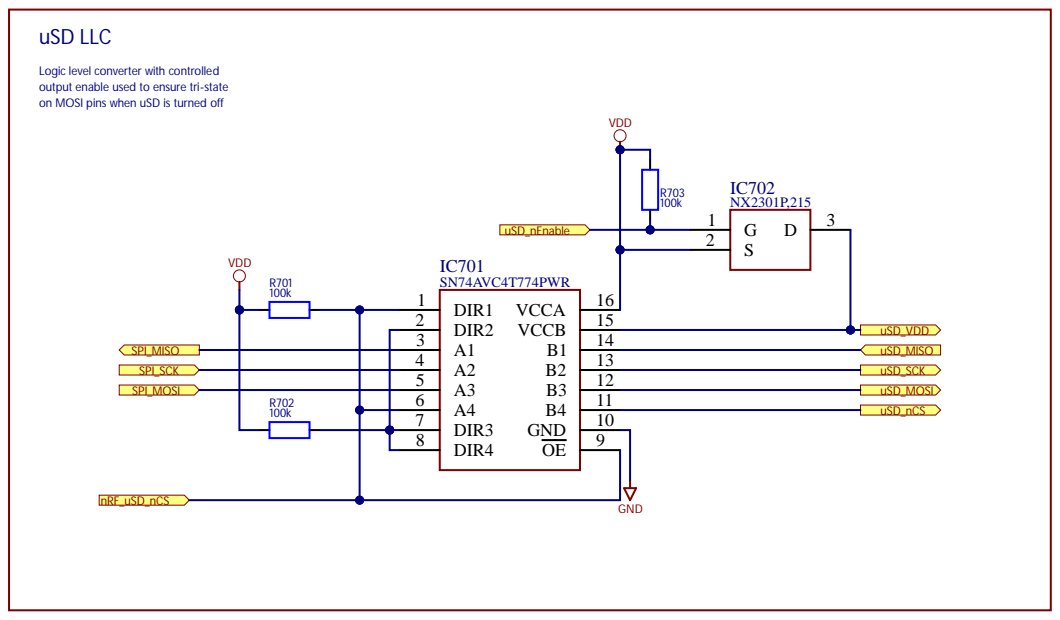
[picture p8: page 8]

Logic level converter with controlled
output enable used to ensure tri-state
on MOSI pins when uSD is turned off

NTNU | Title cSLIM v1 - uSD

Size A4 | Number | Revision v1

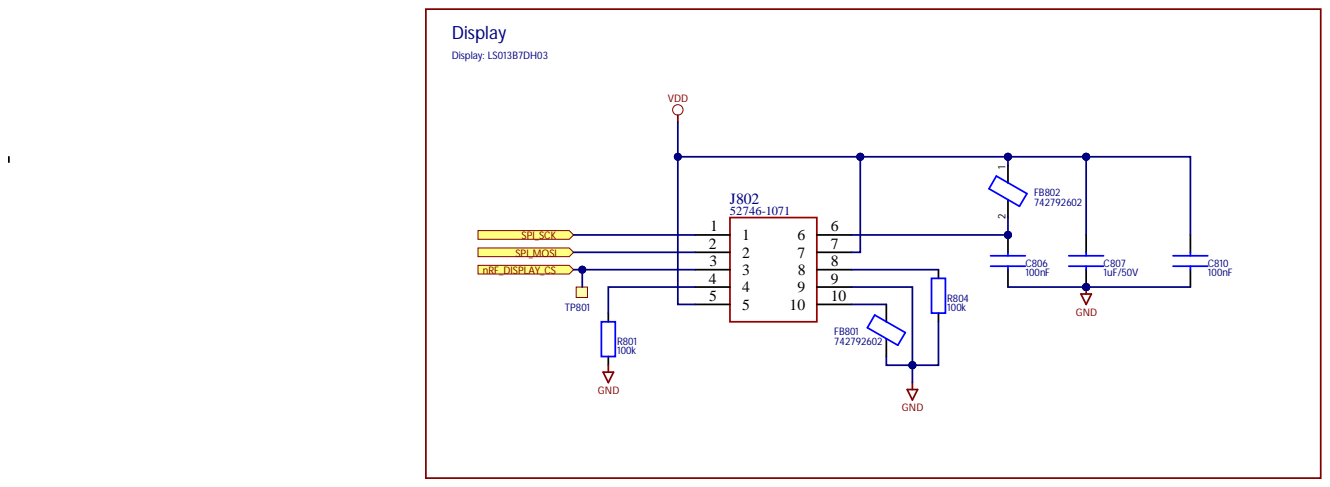
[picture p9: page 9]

NTNU | Title cSLIM v1 - Display

Size A4 | Number | Revision v1

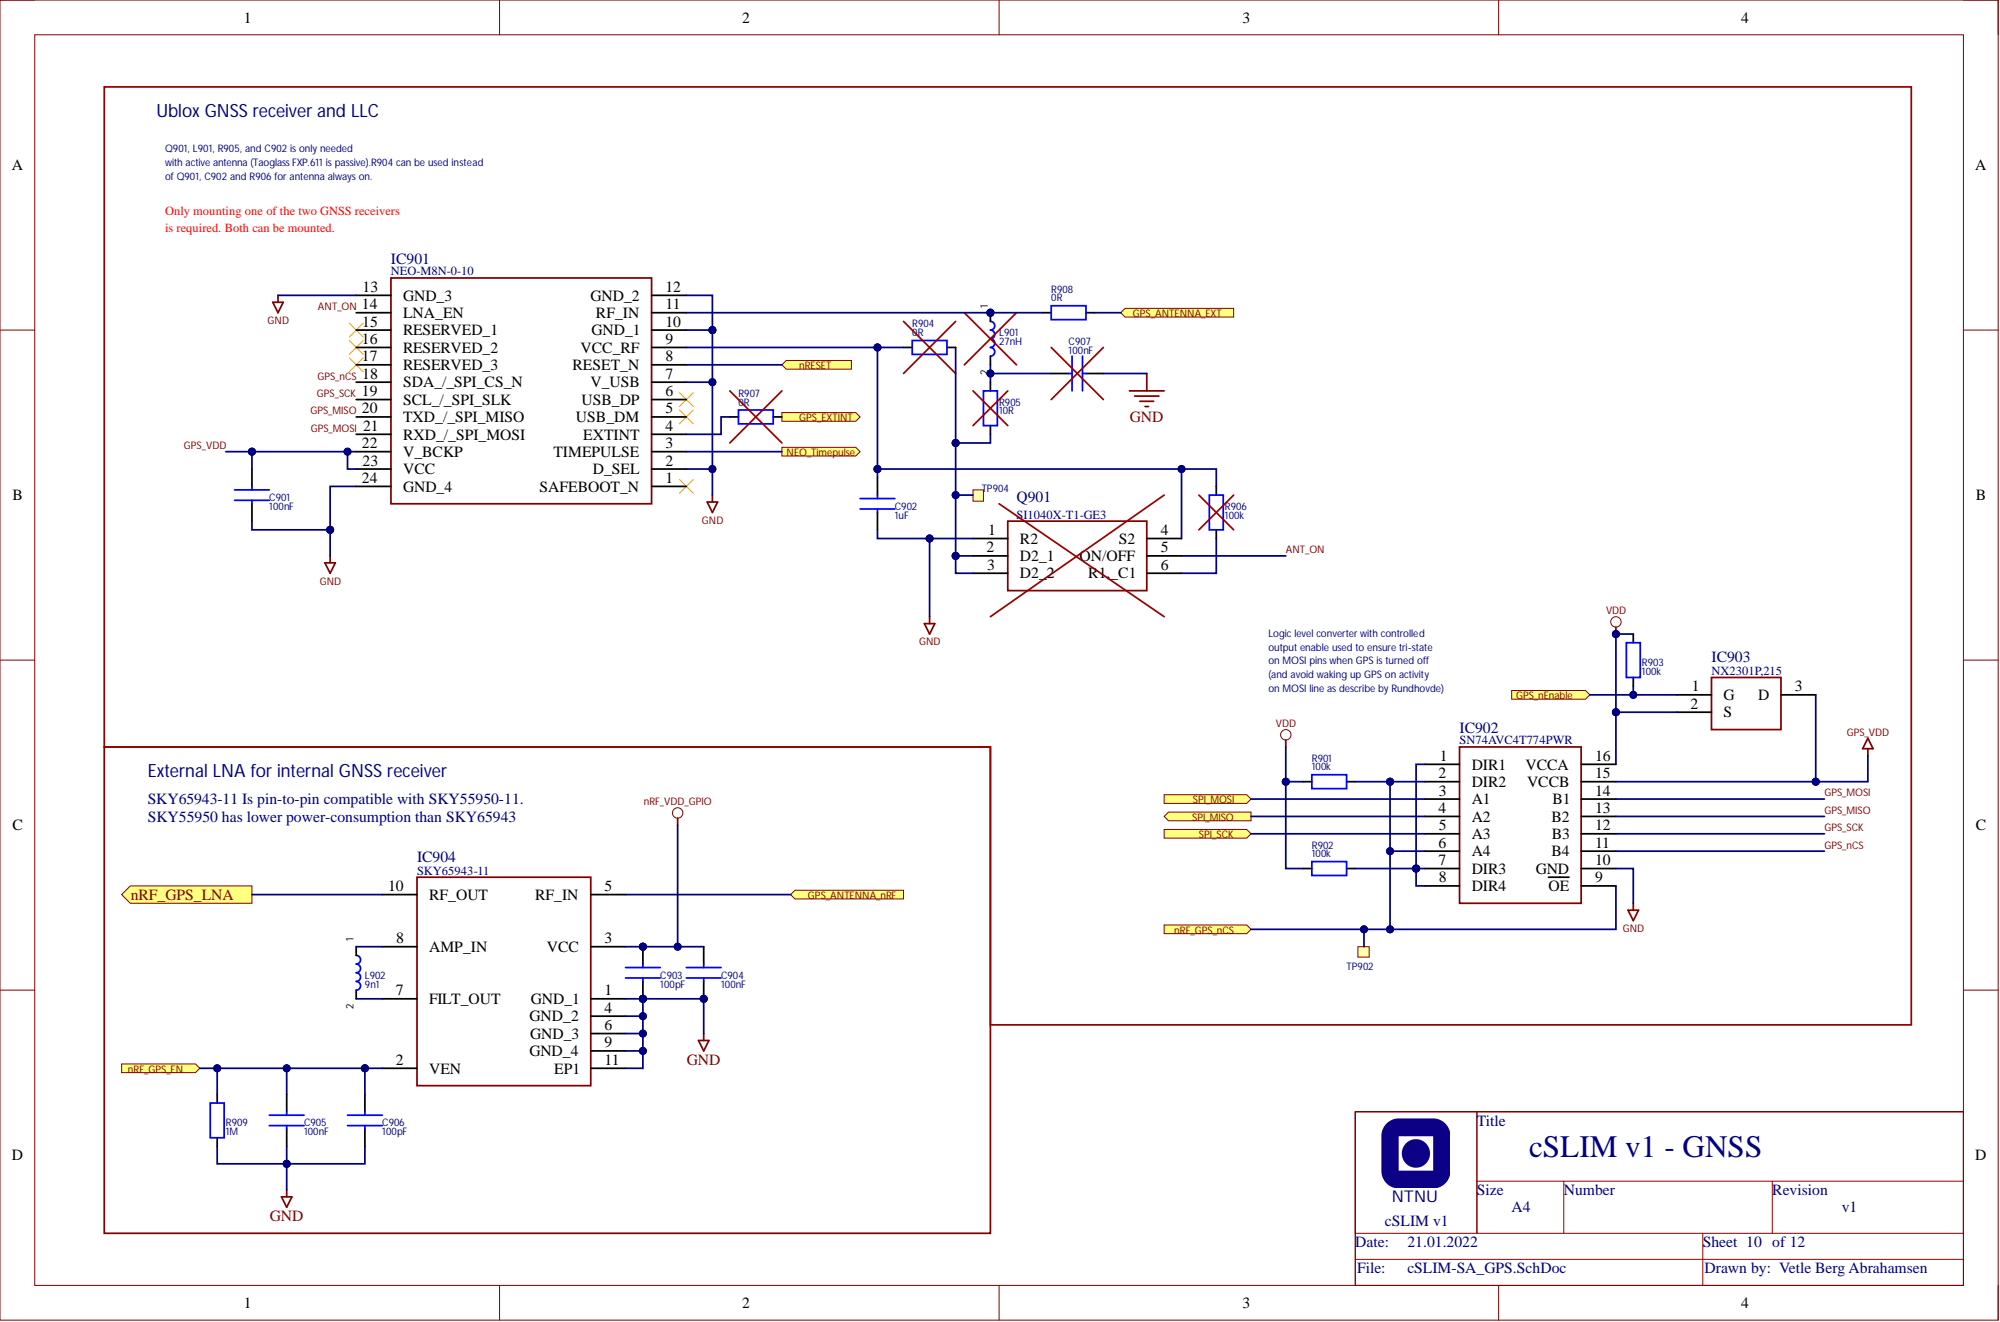
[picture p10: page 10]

Ublox GNSS receiver and LLC

Q901, L901, R905, and C902 is only needed
with active antenna (Taoglass FXP.611 is passive).R904 can be used instead
of Q901, C902 and R906 for antenna always on.

Only mounting one of the two GNSS receivers
is required. Both can be mounted.

Logic level converter with controlled
output enable used to ensure tri-state
on MOSI pins when GPS is turned off
(and avoid waking up GPS on activity
on MOSI line as describe by Rundhovde)

External LNA for internal GNSS receiver

SKY65943-11 Is pin-to-pin compatible with SKY55950-11.
SKY55950 has lower power-consumption than SKY65943

A2 4
A3 5

DIR3 7

NTNU | Title cSLIM v1 - GNSS

Size A4 | Number | Revision v1

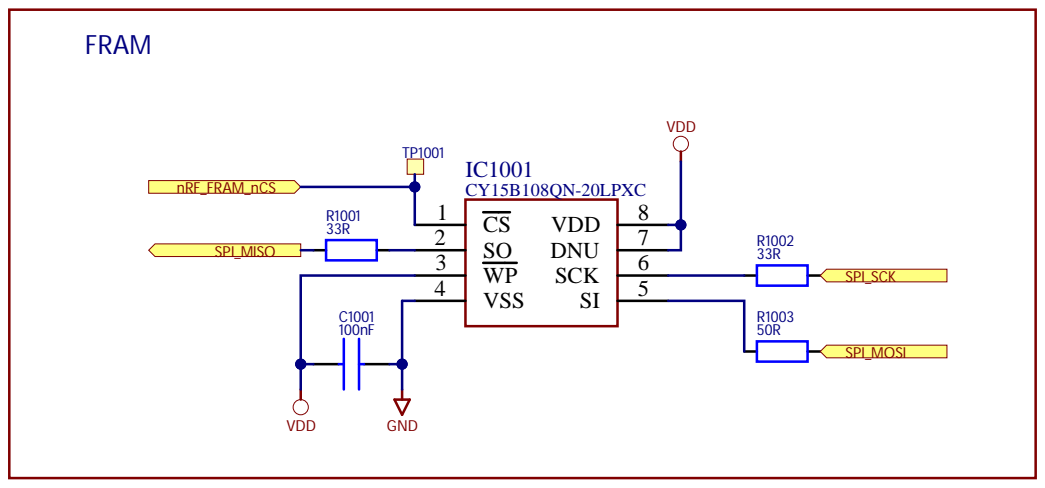
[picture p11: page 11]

NTNU | Title cSLIM v1 - FRAM

Size A4 | Number | Revision v1

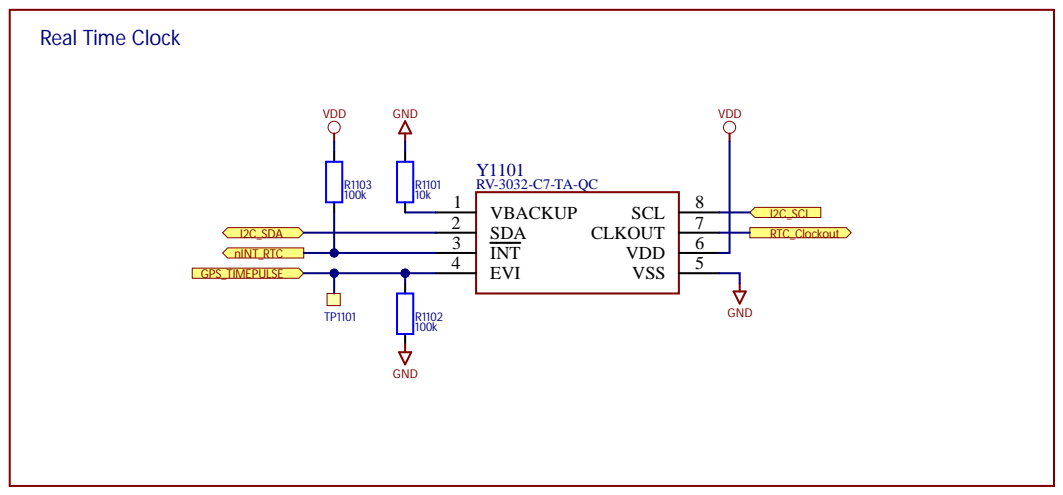
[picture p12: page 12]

NTNU | Title cSLIM v1 - RTC

Size A4 | Number | Revision v1

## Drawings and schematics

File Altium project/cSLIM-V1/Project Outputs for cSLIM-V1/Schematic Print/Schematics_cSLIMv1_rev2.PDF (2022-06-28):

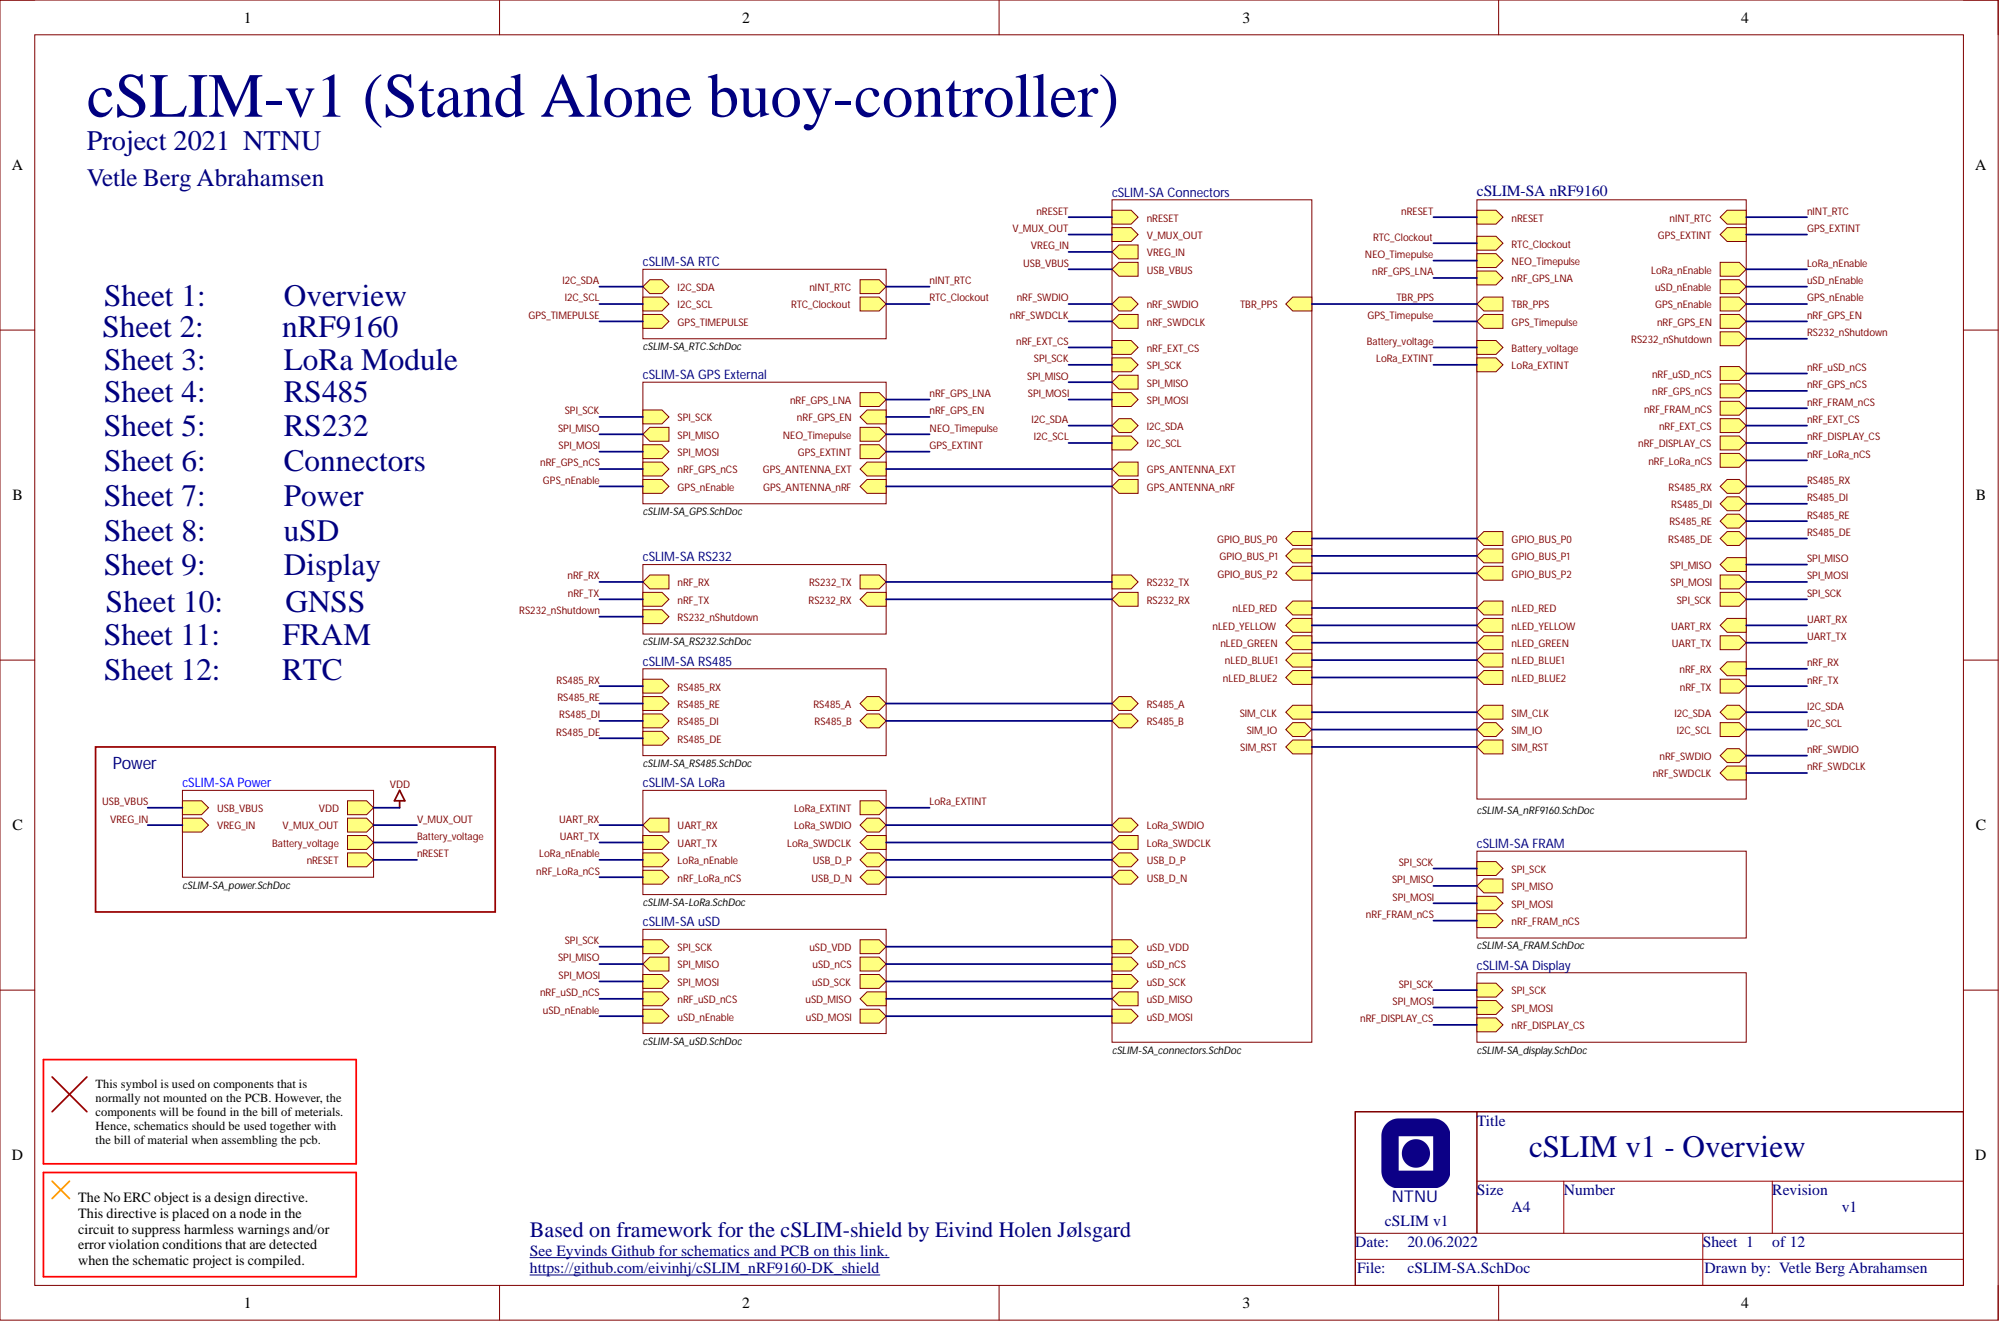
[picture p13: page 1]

cSLIM-v1 (Stand Alone buoy-controller)

cSLIM-SA GPS External

cSLIM-SA-LoRa.SchDoc
cSLIM-SA uSD

This symbol is used on components that is
normally not mounted on the PCB. However, the
components will be found in the bill of meterials.
Hence, schematics should be used together with
the bill of material when assembling the pcb.

NTNU cSLIM v1 | Title cSLIM v1 - Overview

Size A4 | Number | Revision v1

The No ERC object is a design directive.
This directive is placed on a node in the
circuit to suppress harmless warnings and/or
error violation conditions that are detected
when the schematic project is compiled.

Based on framework for the cSLIM-shield by Eivind Holen Jølsgard
See Eyvinds Github for schematics and PCB on this link. (https://github.com/eivinhj/cSLIM_nRF9160-DK_shield)
https://github.com/eivinhj/cSLIM_nRF9160-DK_shield

Date: 20.06.2022 | Sheet of
File: cSLIM-SA.SchDoc | Drawn by: Vetle Berg Abrahamsen

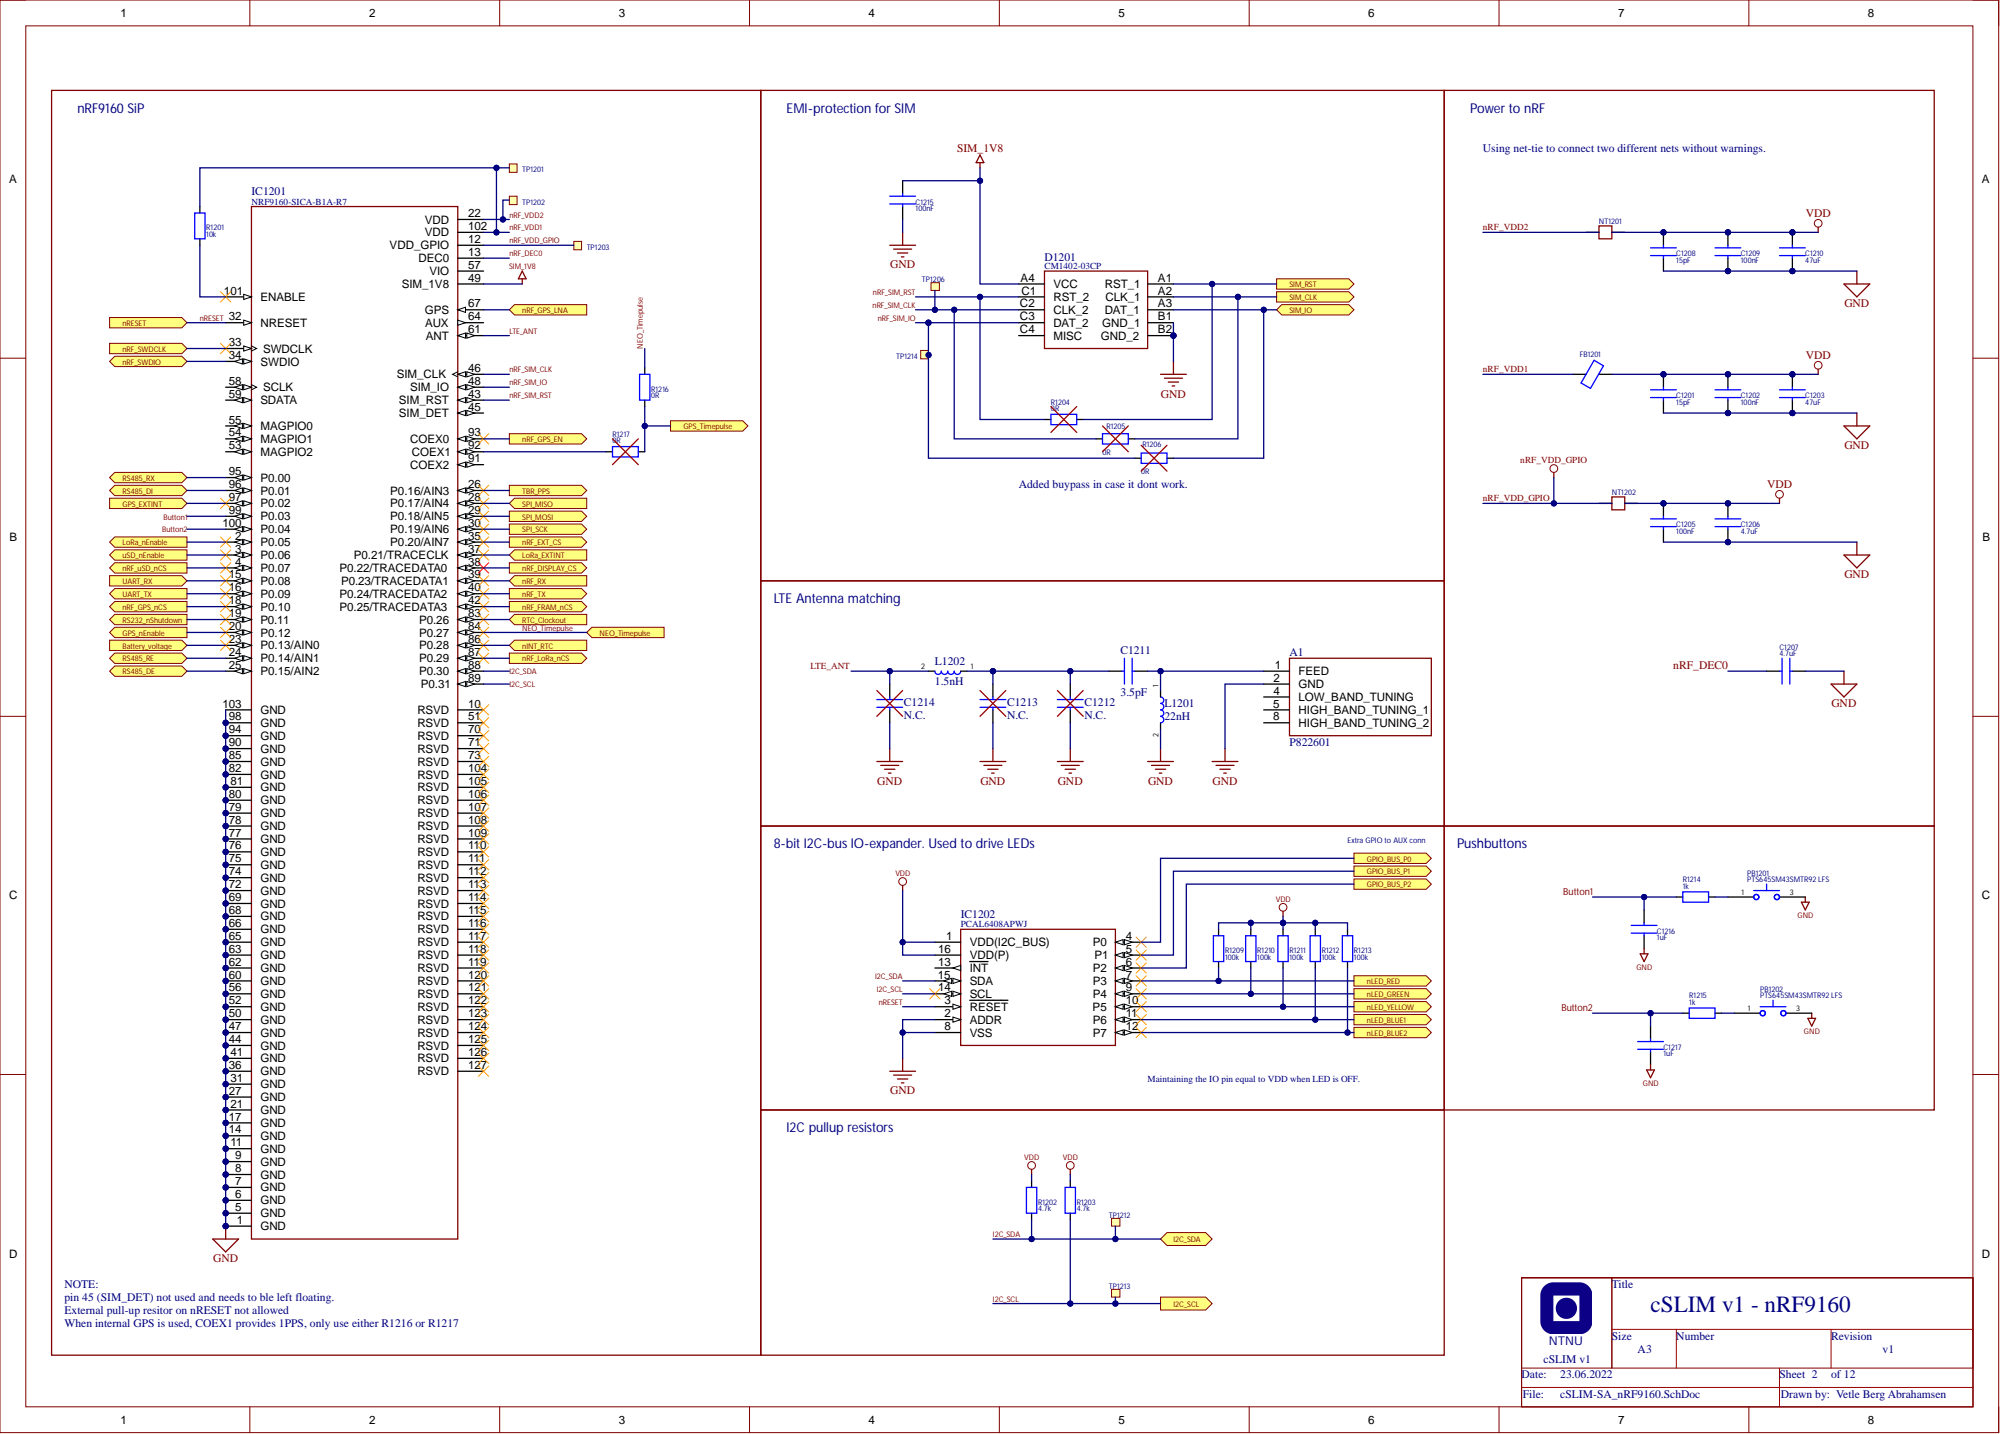
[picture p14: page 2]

EMI-protection for SIM

Using net-tie to connect two different nets without warnings.

MISC C4

Added buypass in case it dont work.

8-bit I2C-bus IO-expander. Used to drive LEDs

Extra GPIO to AUX conn

Maintaining the IO pin equal to VDD when LED is OFF.

NOTE:
pin 45 (SIM_DET) not used and needs to ble left floating.
External pull-up resitor on nRESET not allowed
When internal GPS is used, COEX1 provides 1PPS, only use either R1216 or R1217

NTNU | Title cSLIM v1 - nRF9160

Size A3 | Number | Revision v1

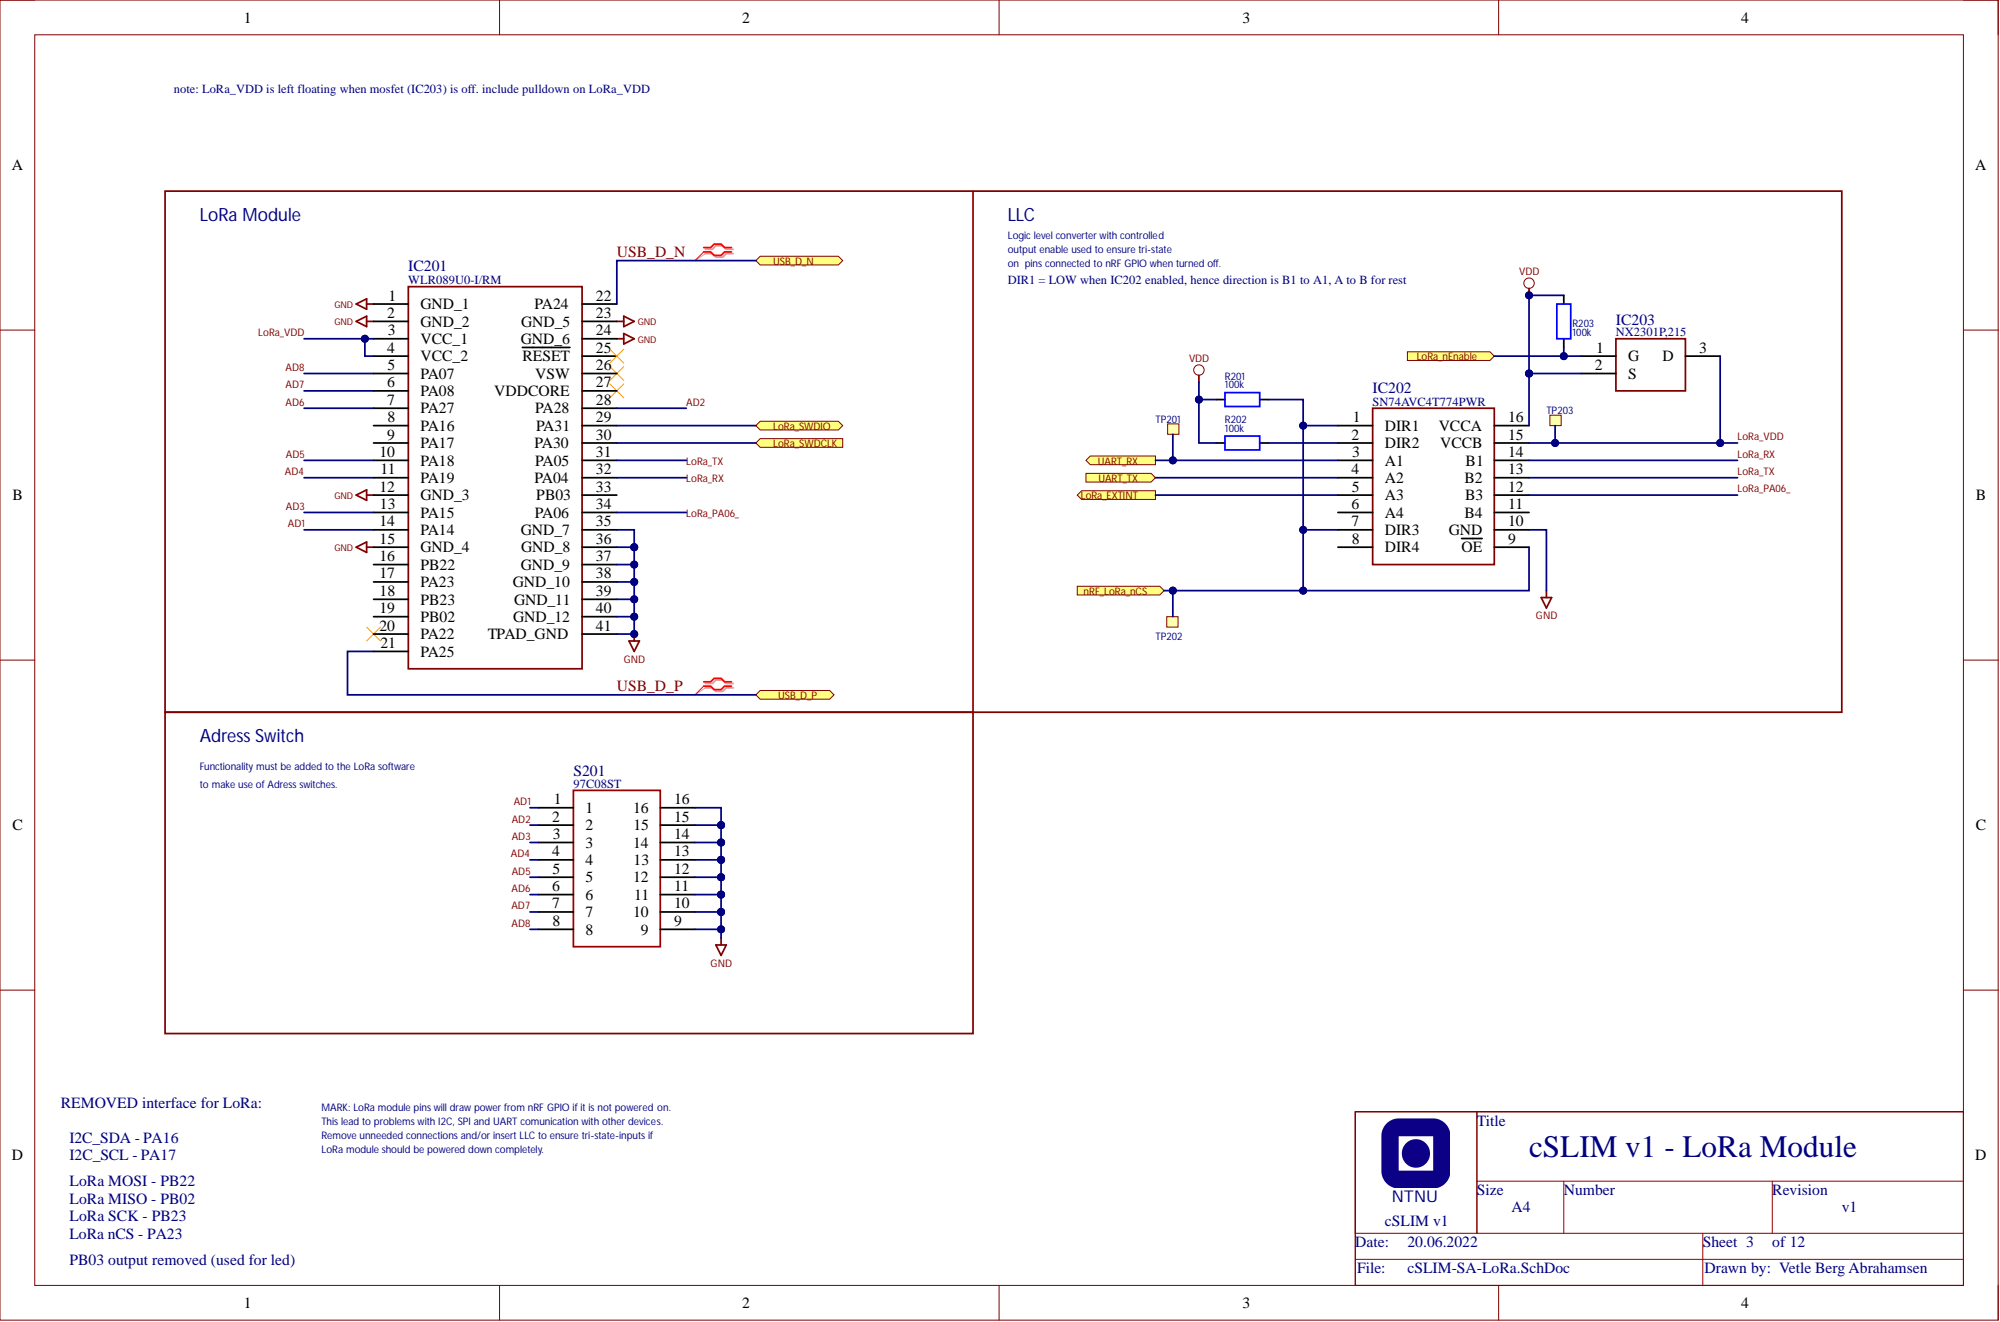
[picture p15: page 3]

note: LoRa_VDD is left floating when mosfet (IC203) is off. include pulldown on LoRa_VDD

output enable used to ensure tri-state
on pins connected to nRF GPIO when turned off.
DIR1 = LOW when IC202 enabled, hence direction is B1 to A1, A to B for rest

Functionality must be added to the LoRa software
to make use of Adress switches.

REMOVED interface for LoRa:

MARK: LoRa module pins will draw power from nRF GPIO if it is not powered on.
This lead to problems with I2C, SPI and UART comunication with other devices.
Remove unneeded connections and/or insert LLC to ensure tri-state-inputs if
LoRa module should be powered down completely.

NTNU | Title cSLIM v1 - LoRa Module

Size A4 | Number | Revision v1

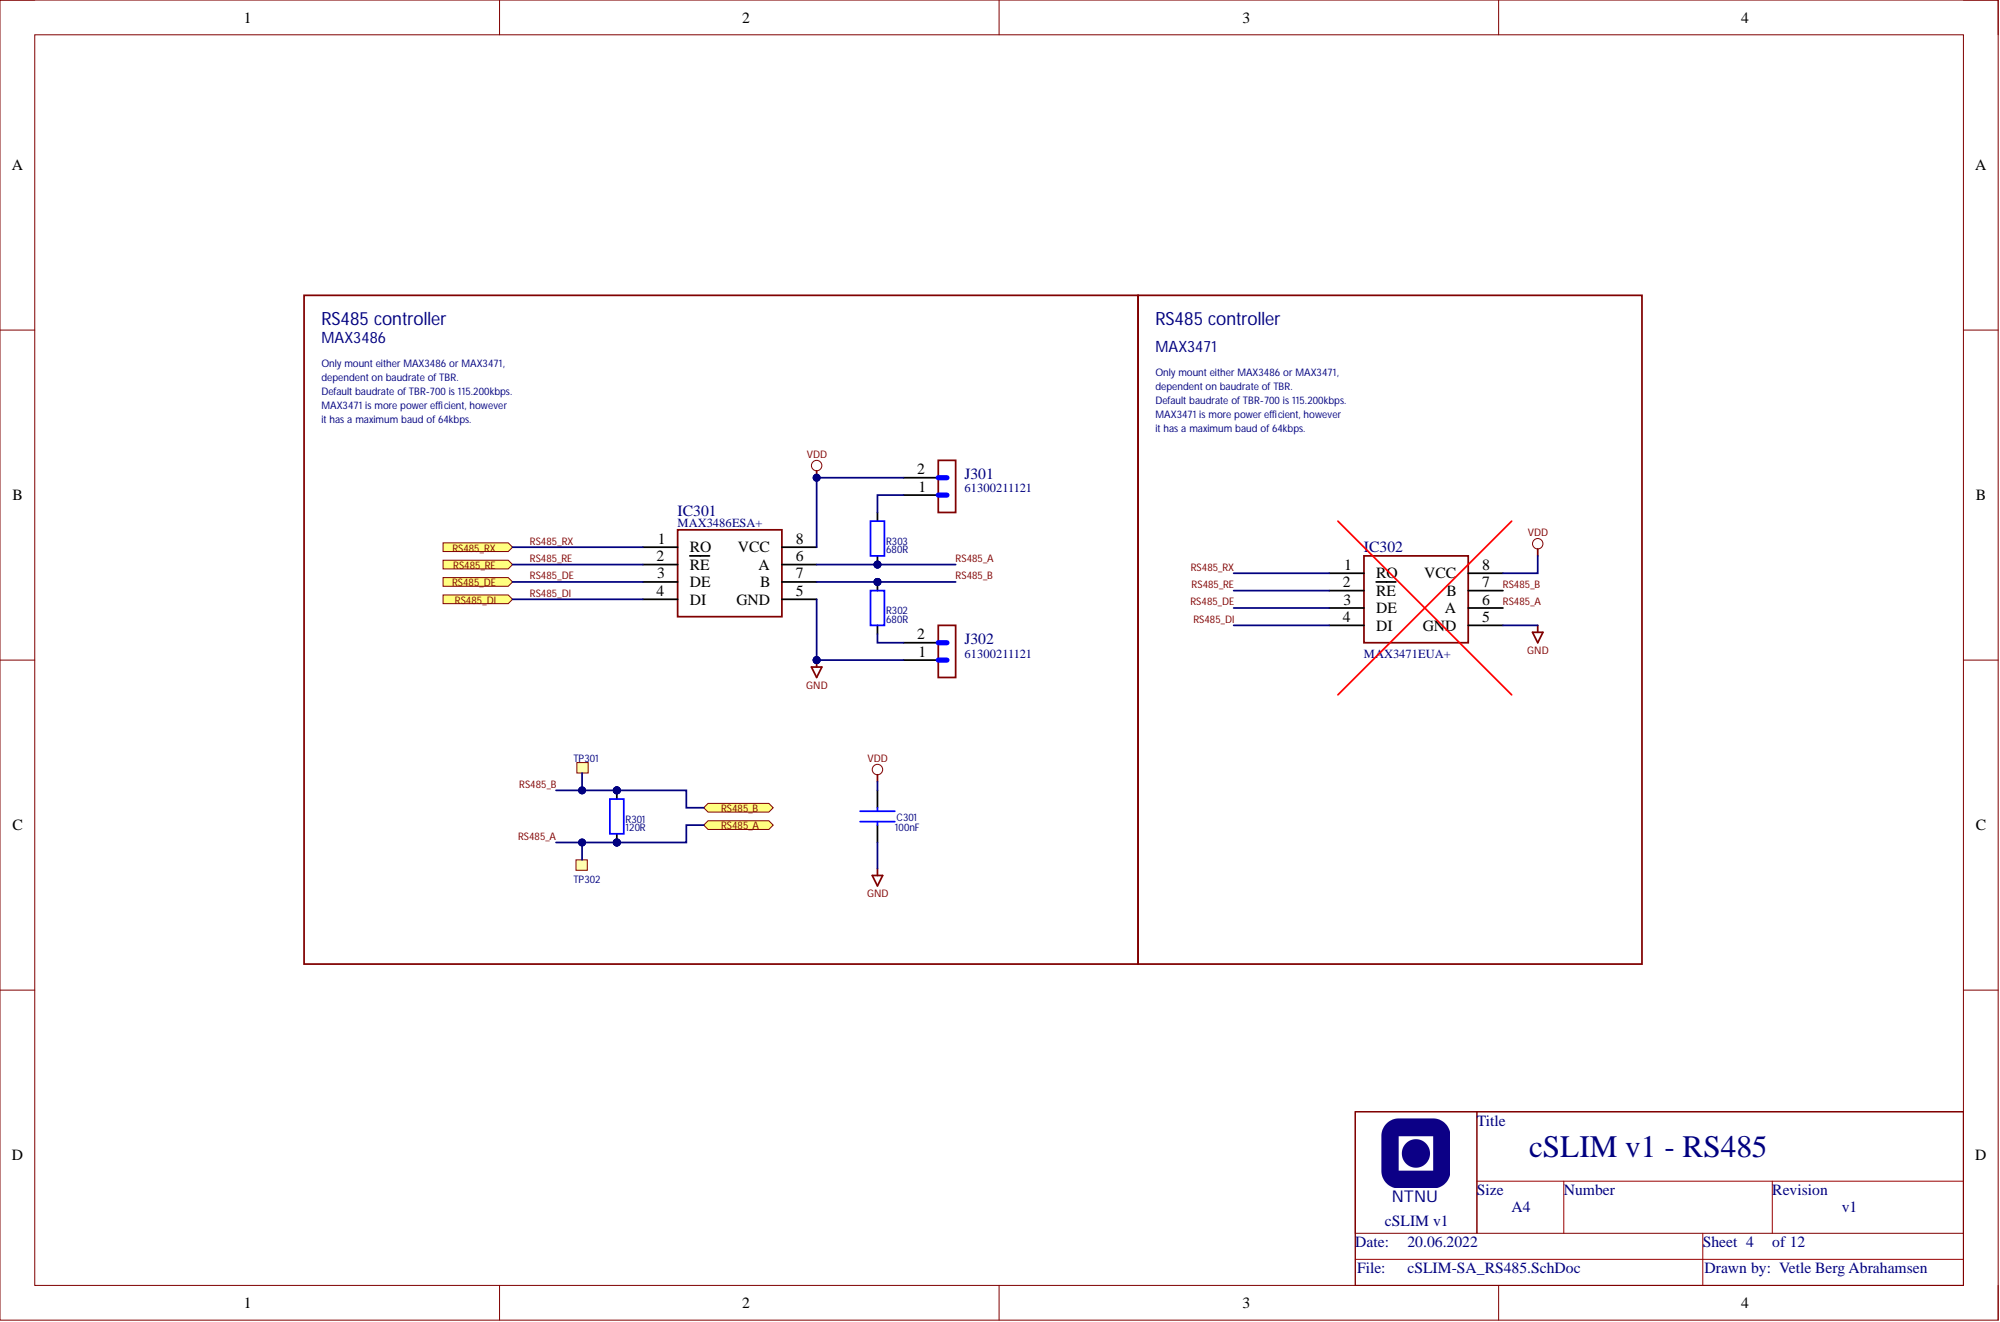
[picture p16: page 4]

Only mount either MAX3486 or MAX3471,
dependent on baudrate of TBR.
Default baudrate of TBR-700 is 115.200kbps.
MAX3471 is more power efficient, however
it has a maximum baud of 64kbps.

VDD | VDD IC302

NTNU | Title cSLIM v1 - RS485

Size A4 | Number | Revision v1


Note: The nEN pin connected to ground should
be considered to be controlled by the nRF
for future designs

NTNU | Title cSLIM v1 - RS232

Size A4 | Number | Revision v1

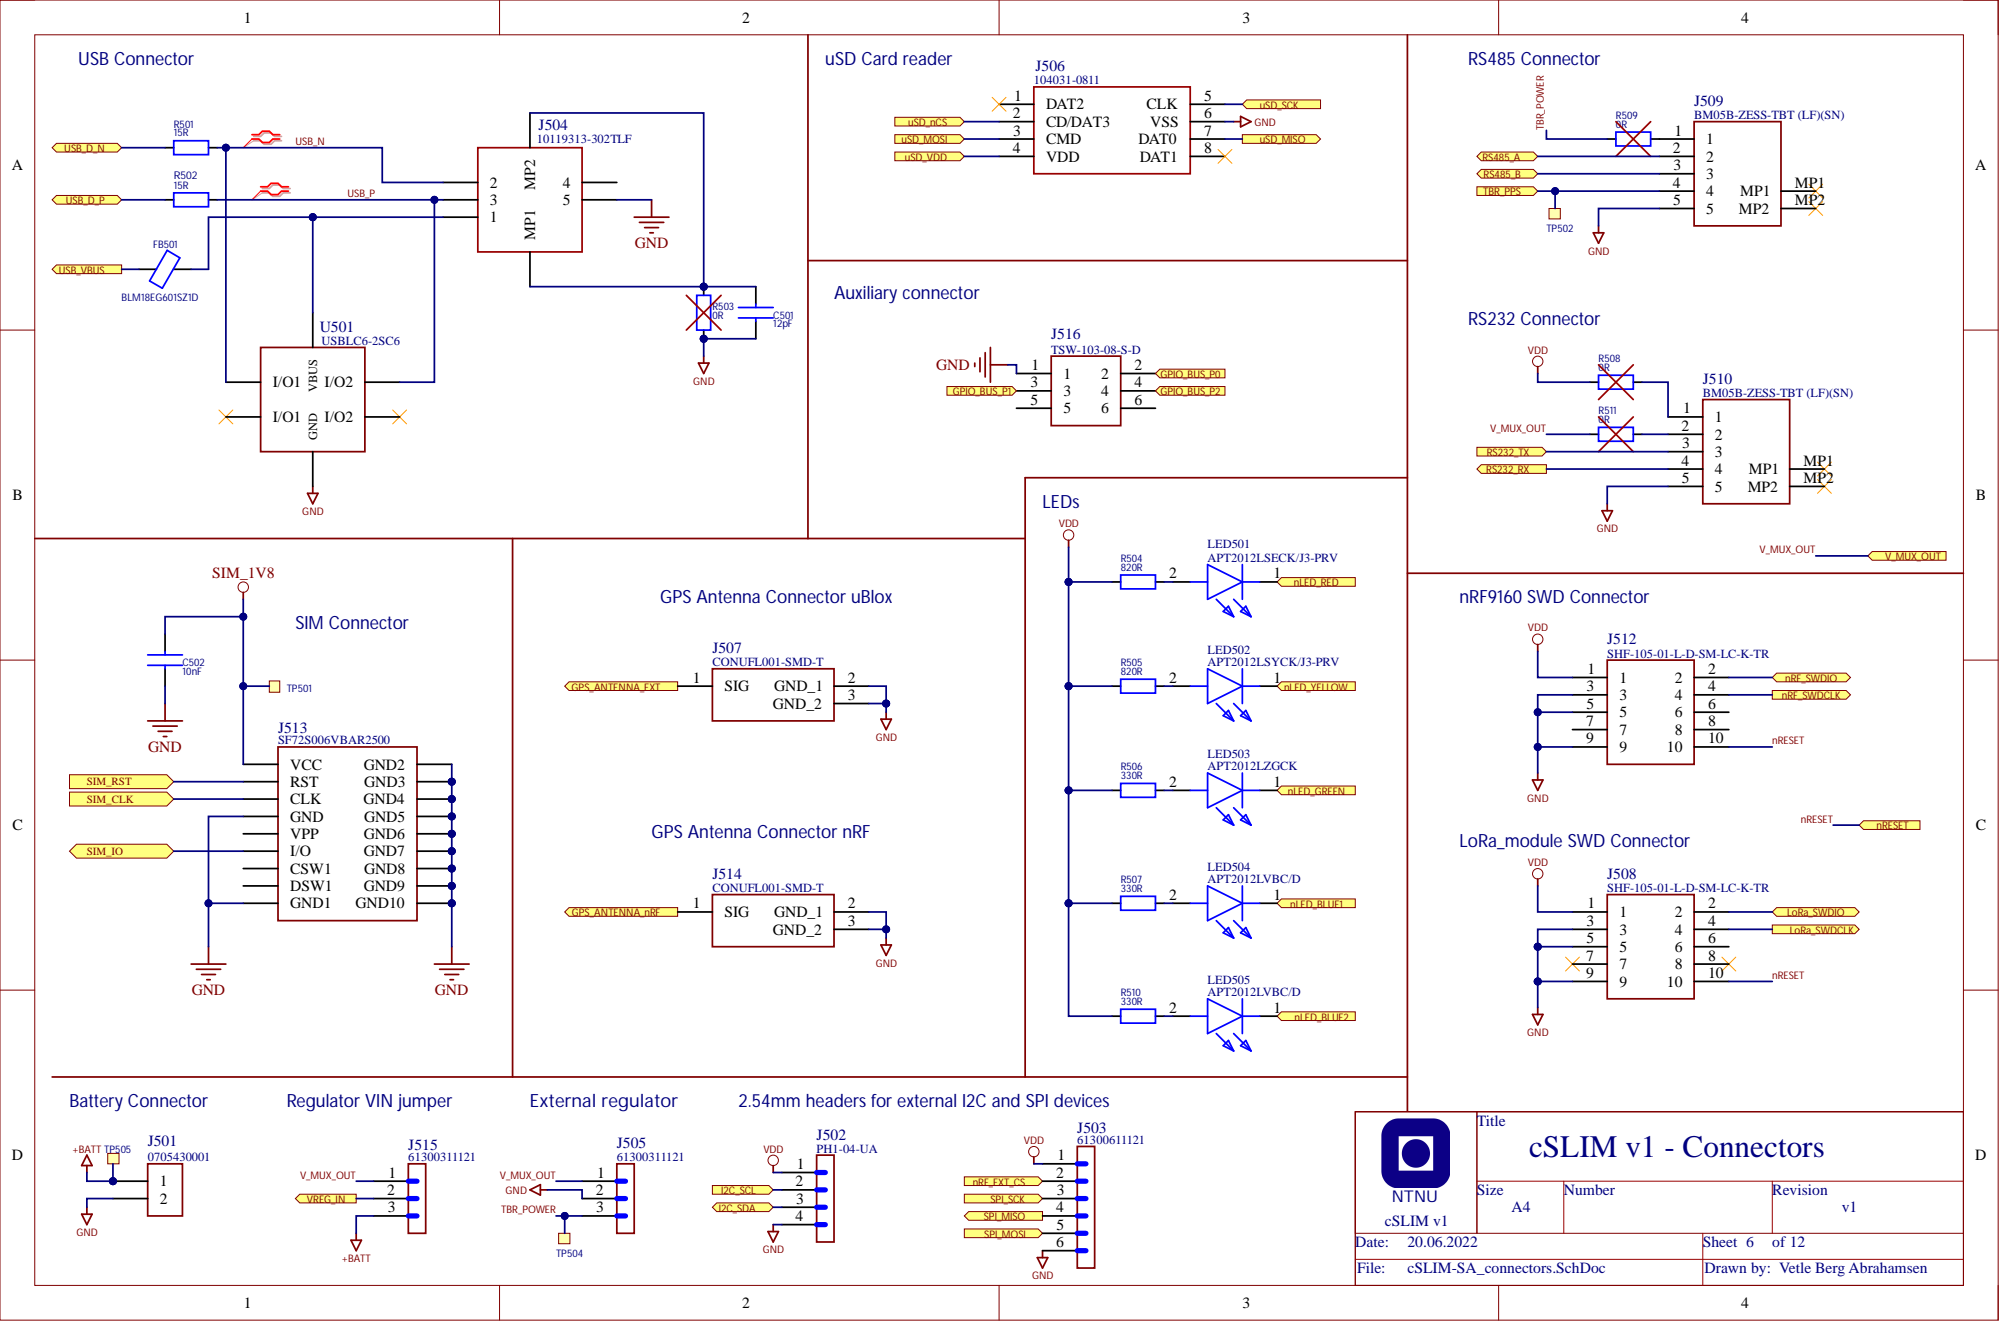
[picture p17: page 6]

GPS Antenna Connector uBlox

SHF-105-01-L-D-SM-LC-K-TR

GPS Antenna Connector nRF

2.54mm headers for external I2C and SPI devices

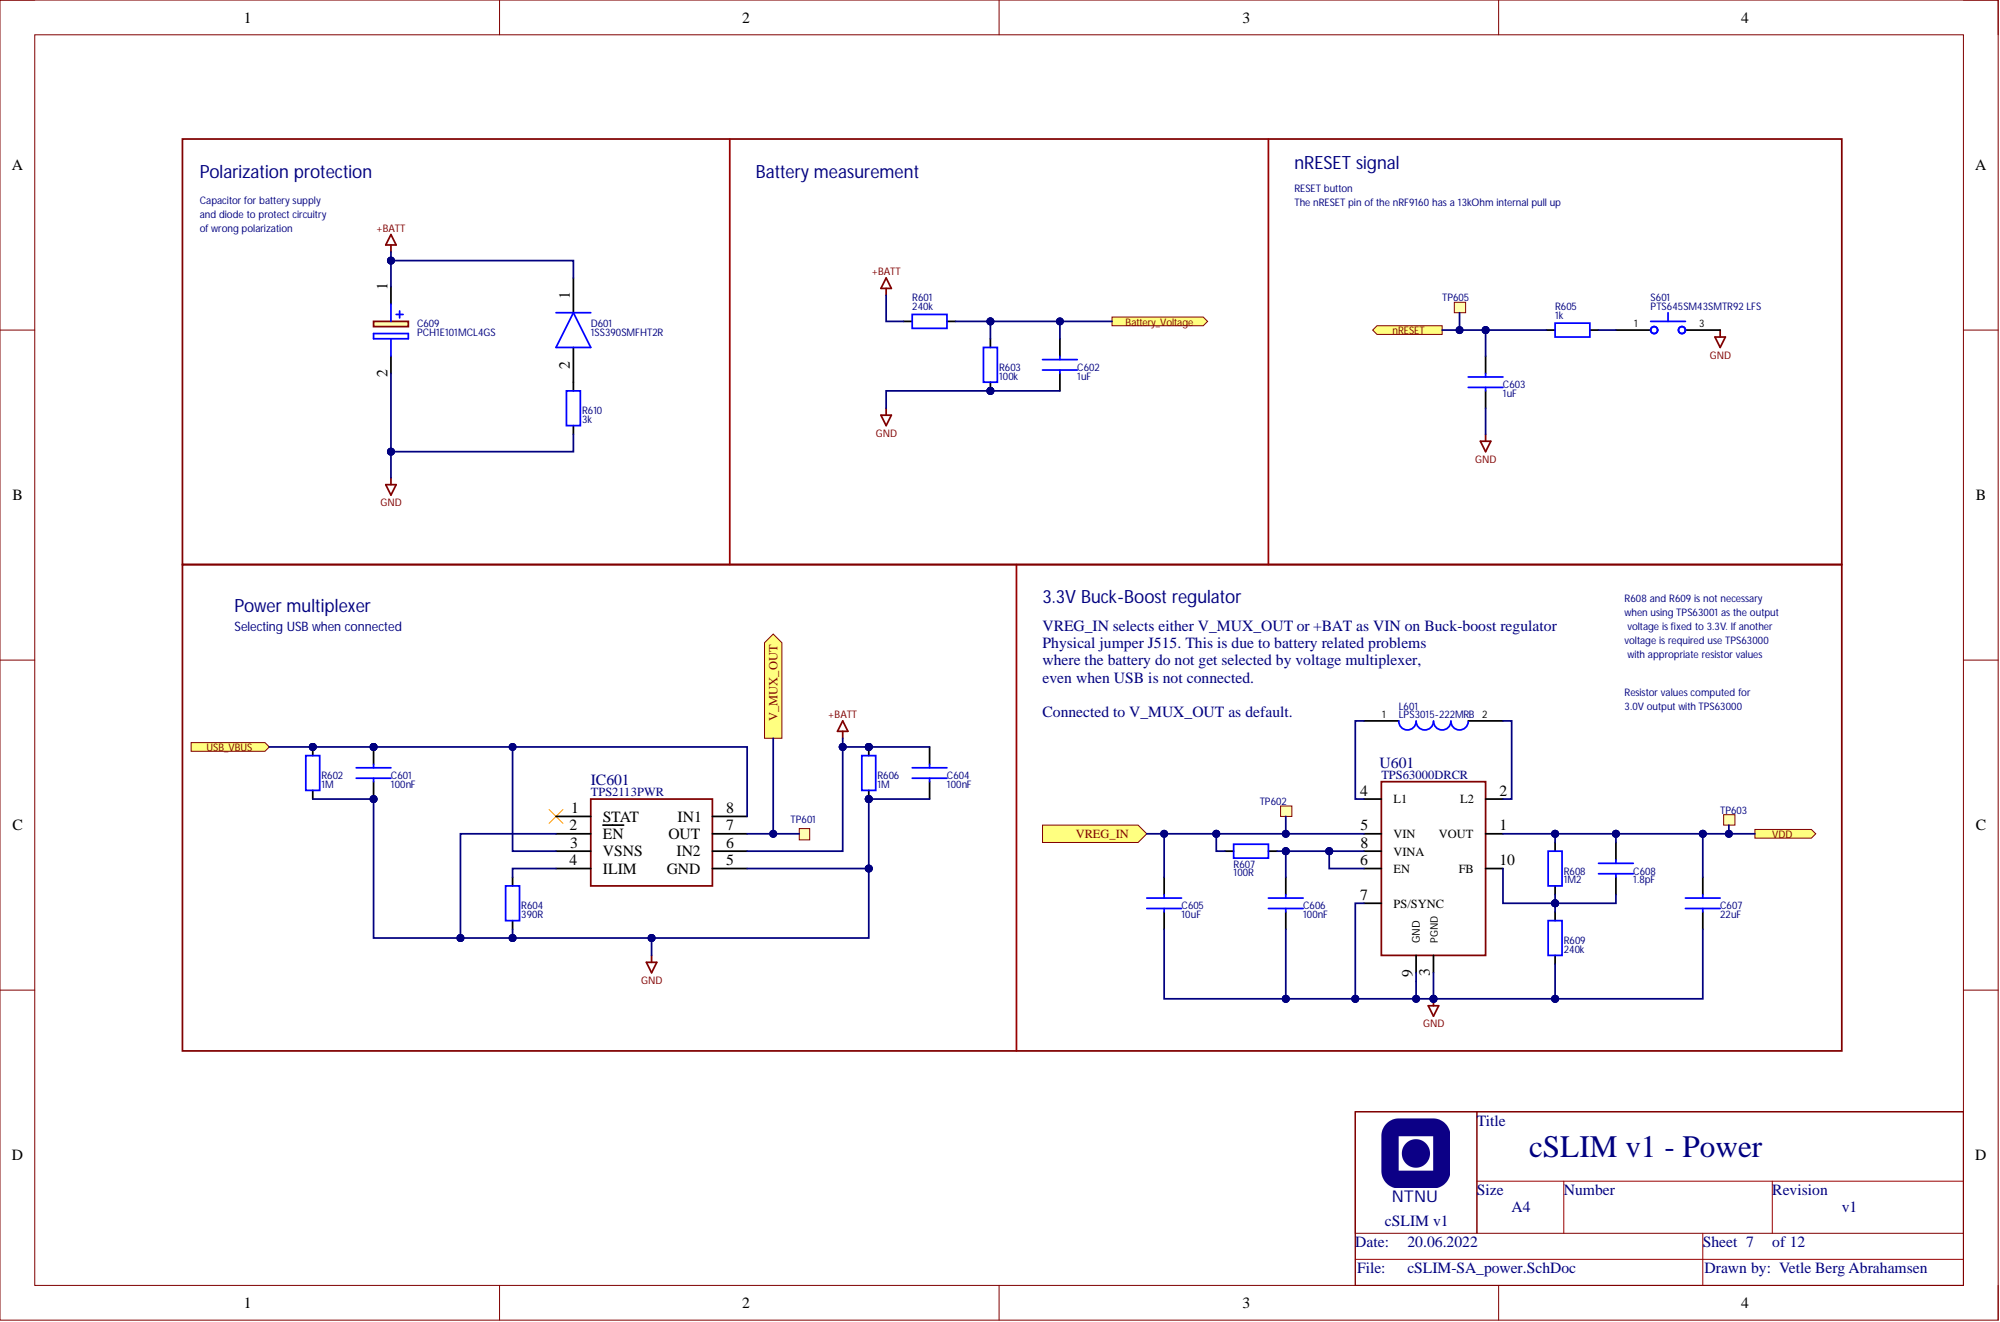
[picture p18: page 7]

Capacitor for battery supply
and diode to protect circuitry
of wrong polarization

RESET button
The nRESET pin of the nRF9160 has a 13kOhm internal pull up

R608 and R609 is not necessary
when using TPS63001 as the output
voltage is fixed to 3.3V. If another
voltage is required use TPS63000
with appropriate resistor values

Selecting USB when connected

VREG_IN selects either V_MUX_OUT or +BAT as VIN on Buck-boost regulator
Physical jumper J515. This is due to battery related problems
where the battery do not get selected by voltage multiplexer,
even when USB is not connected.

Resistor values computed for
3.0V output with TPS63000

Connected to V_MUX_OUT as default.

EN 2 OUT | 7

ILIM 4

NTNU | Title cSLIM v1 - Power

Size A4 | Number | Revision v1


Logic level converter with controlled
output enable used to ensure tri-state
on MOSI pins when uSD is turned off

NTNU | Title cSLIM v1 - uSD

Size A4 | Number | Revision v1


NTNU | Title cSLIM v1 - Display

Size A4 | Number | Revision v1

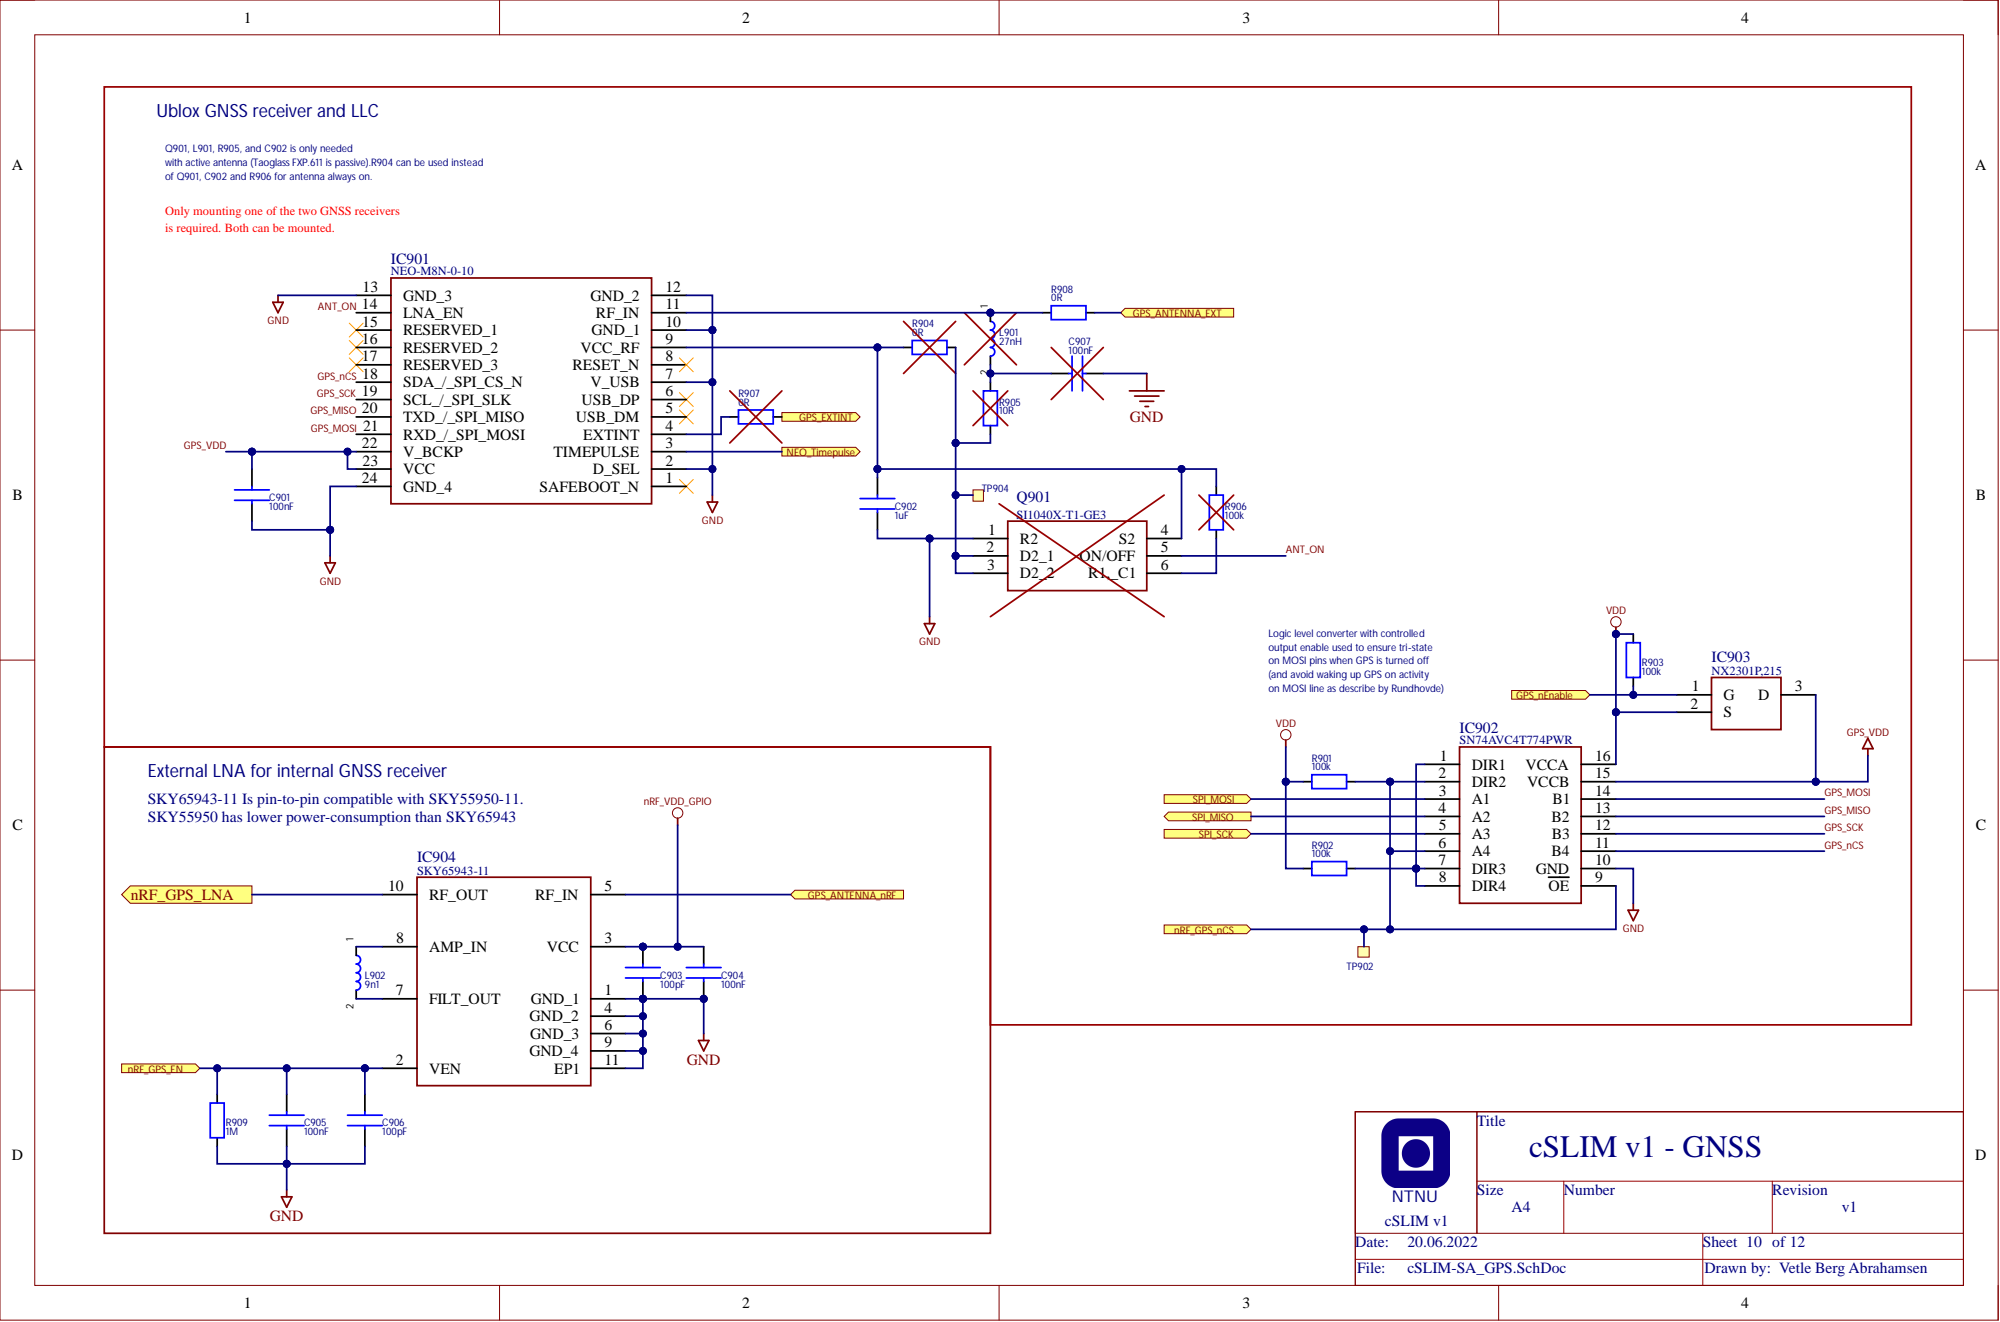
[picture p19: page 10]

Ublox GNSS receiver and LLC

Q901, L901, R905, and C902 is only needed
with active antenna (Taoglass FXP.611 is passive).R904 can be used instead
of Q901, C902 and R906 for antenna always on.

Only mounting one of the two GNSS receivers
is required. Both can be mounted.

Logic level converter with controlled
output enable used to ensure tri-state
on MOSI pins when GPS is turned off
(and avoid waking up GPS on activity
on MOSI line as describe by Rundhovde)

External LNA for internal GNSS receiver
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

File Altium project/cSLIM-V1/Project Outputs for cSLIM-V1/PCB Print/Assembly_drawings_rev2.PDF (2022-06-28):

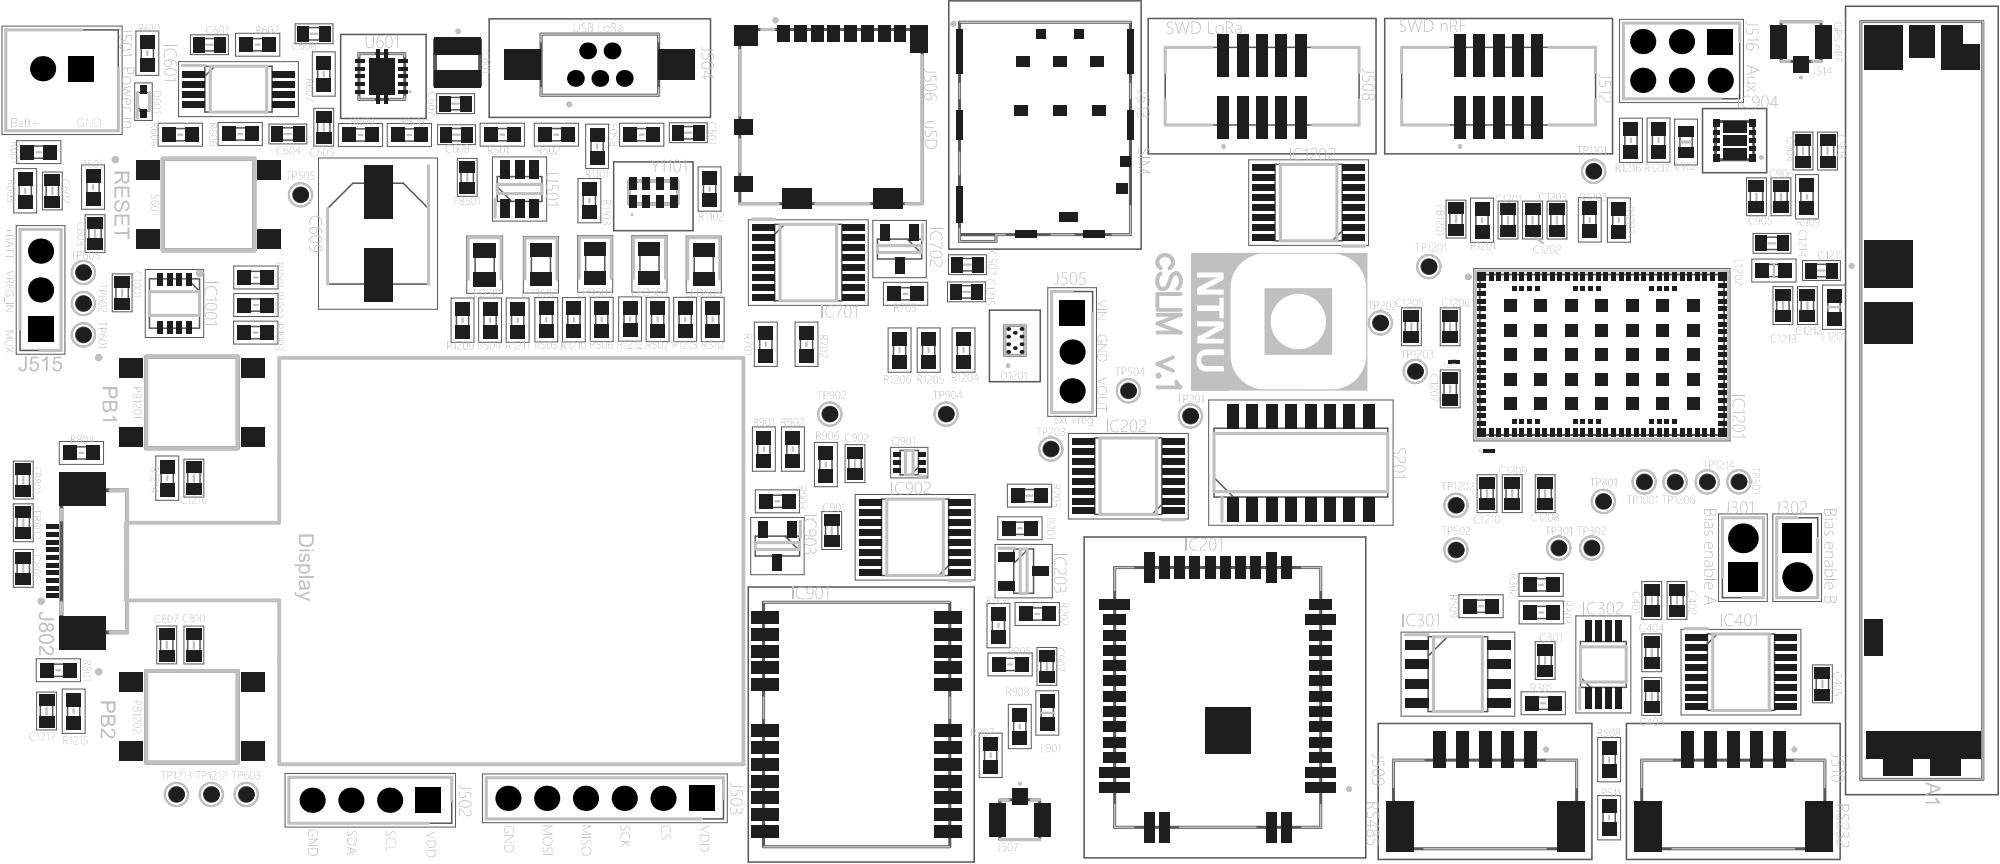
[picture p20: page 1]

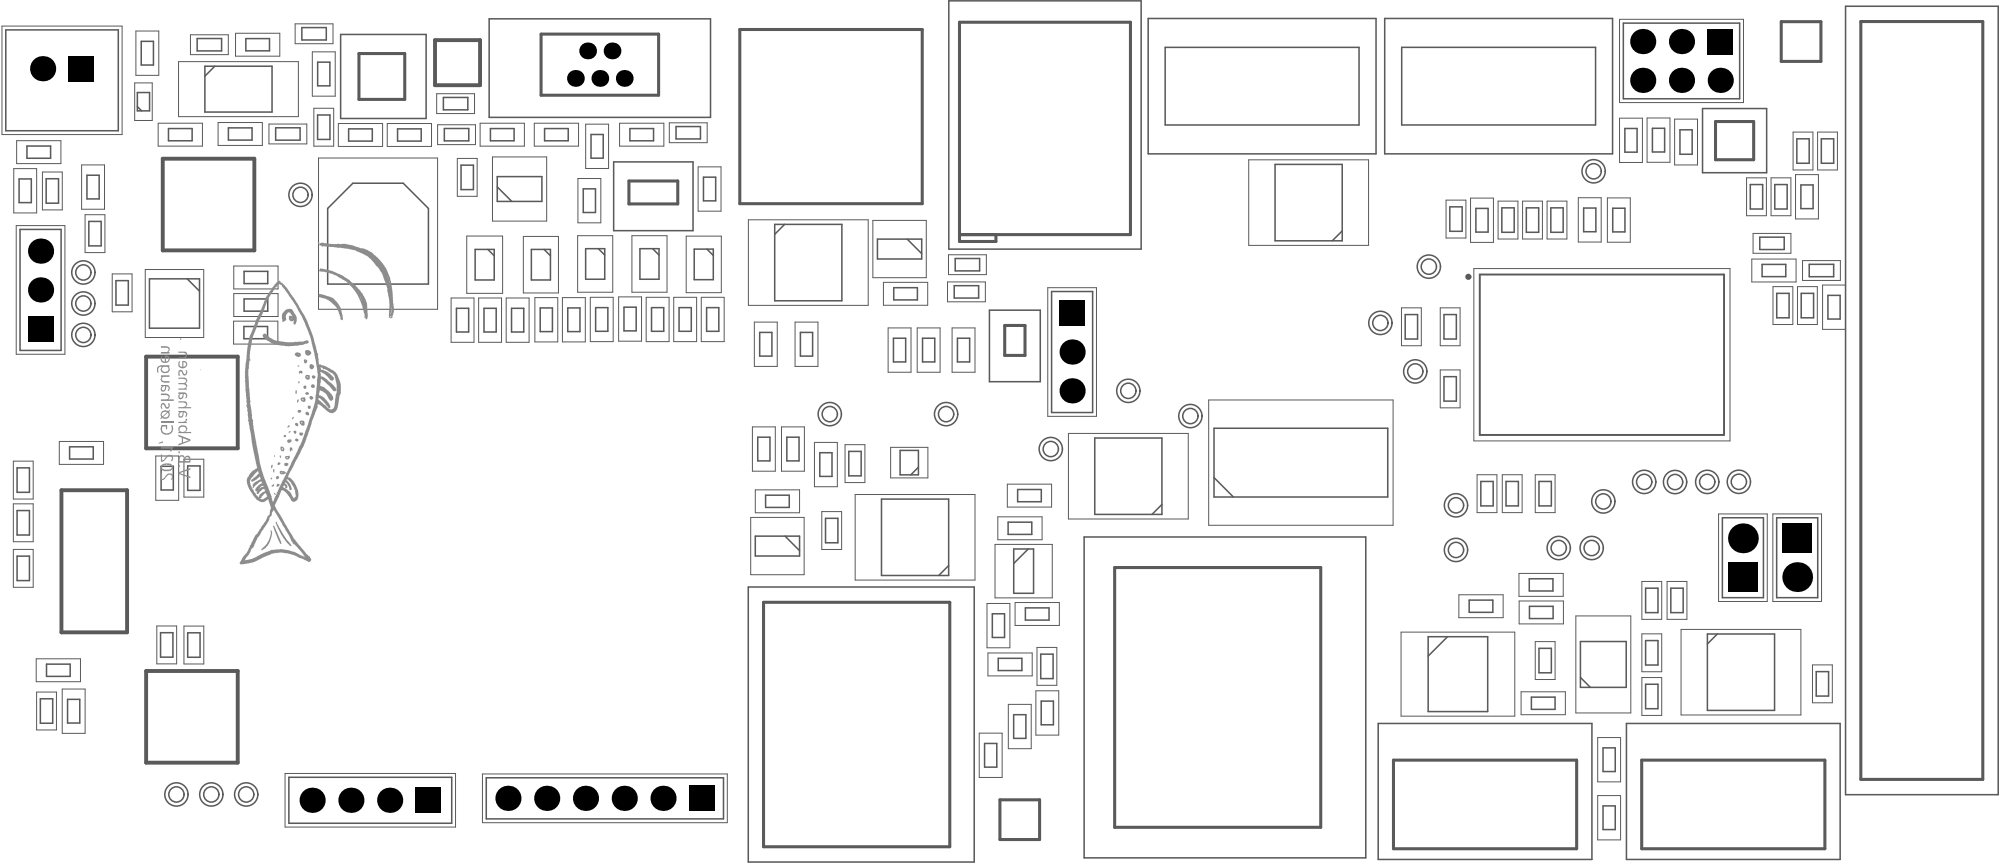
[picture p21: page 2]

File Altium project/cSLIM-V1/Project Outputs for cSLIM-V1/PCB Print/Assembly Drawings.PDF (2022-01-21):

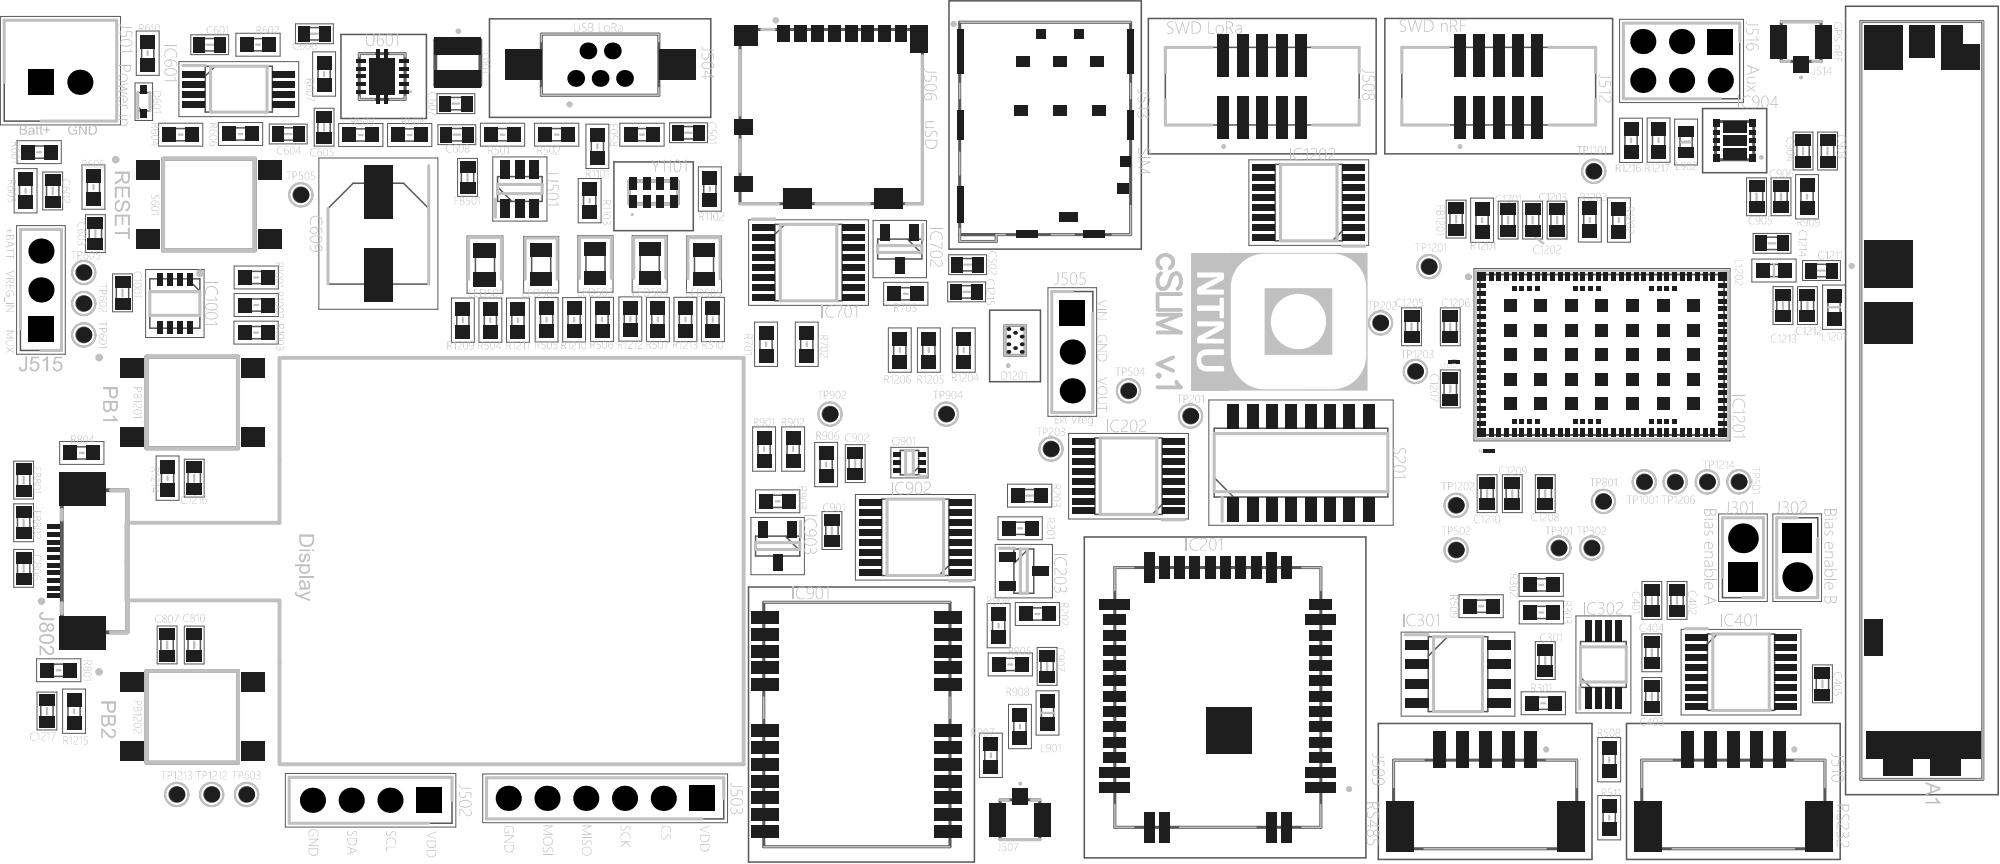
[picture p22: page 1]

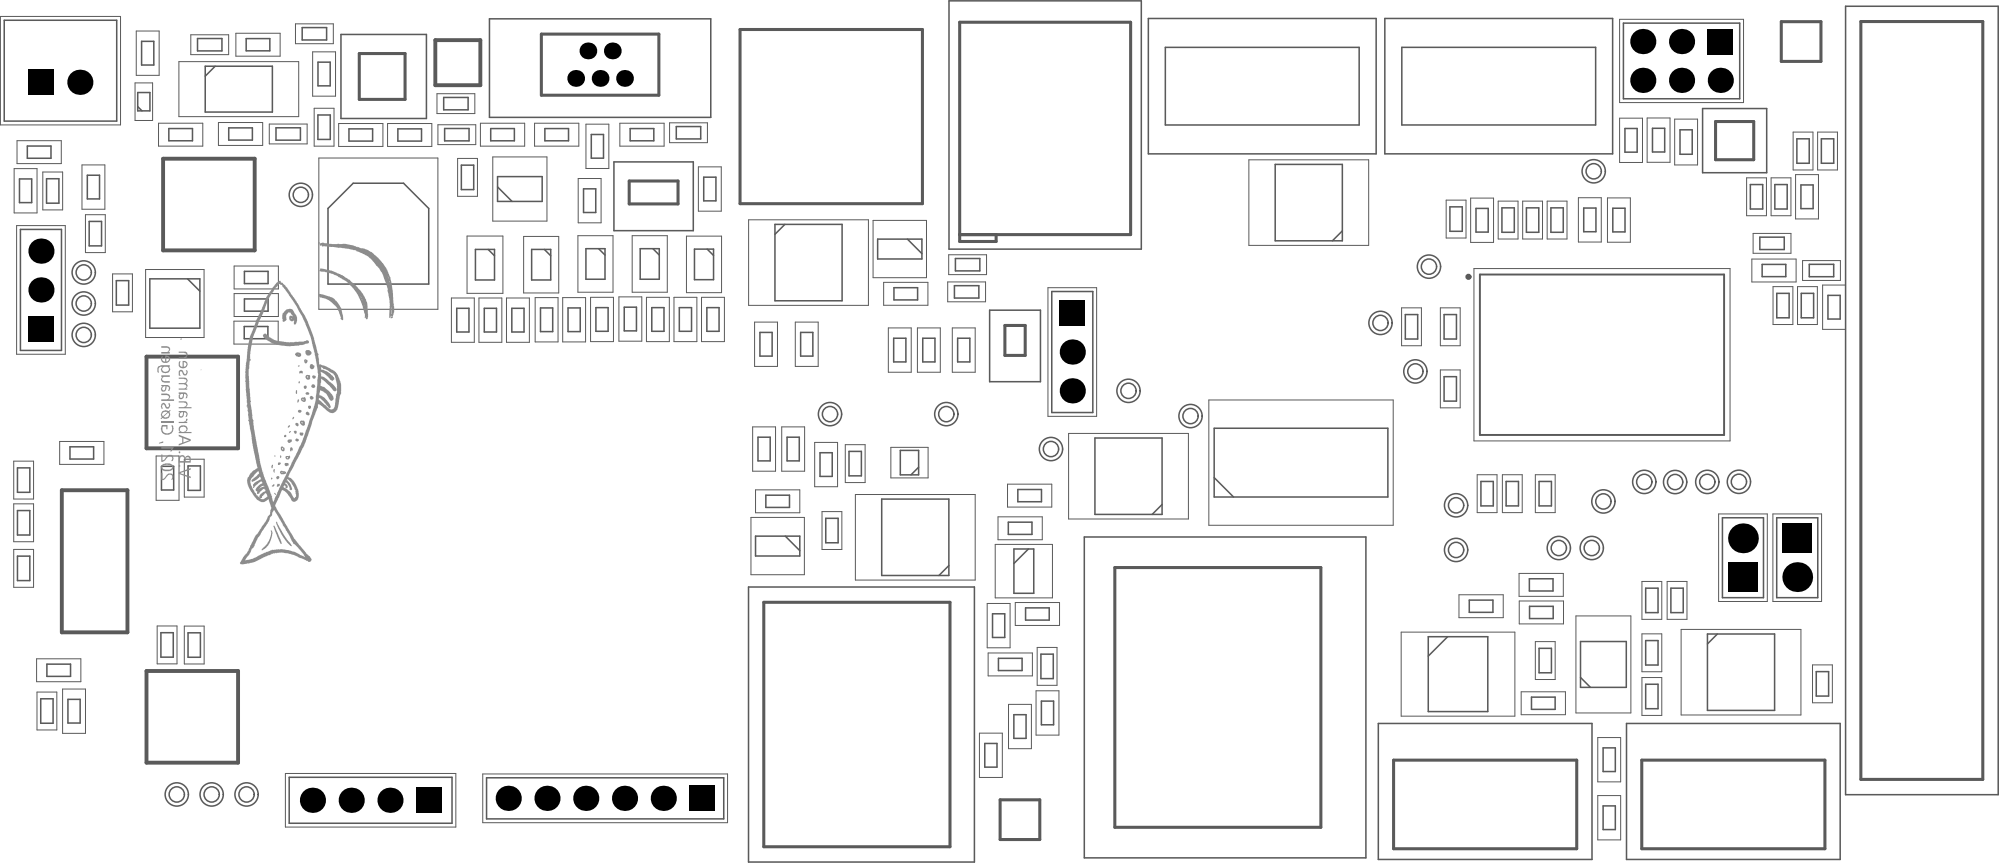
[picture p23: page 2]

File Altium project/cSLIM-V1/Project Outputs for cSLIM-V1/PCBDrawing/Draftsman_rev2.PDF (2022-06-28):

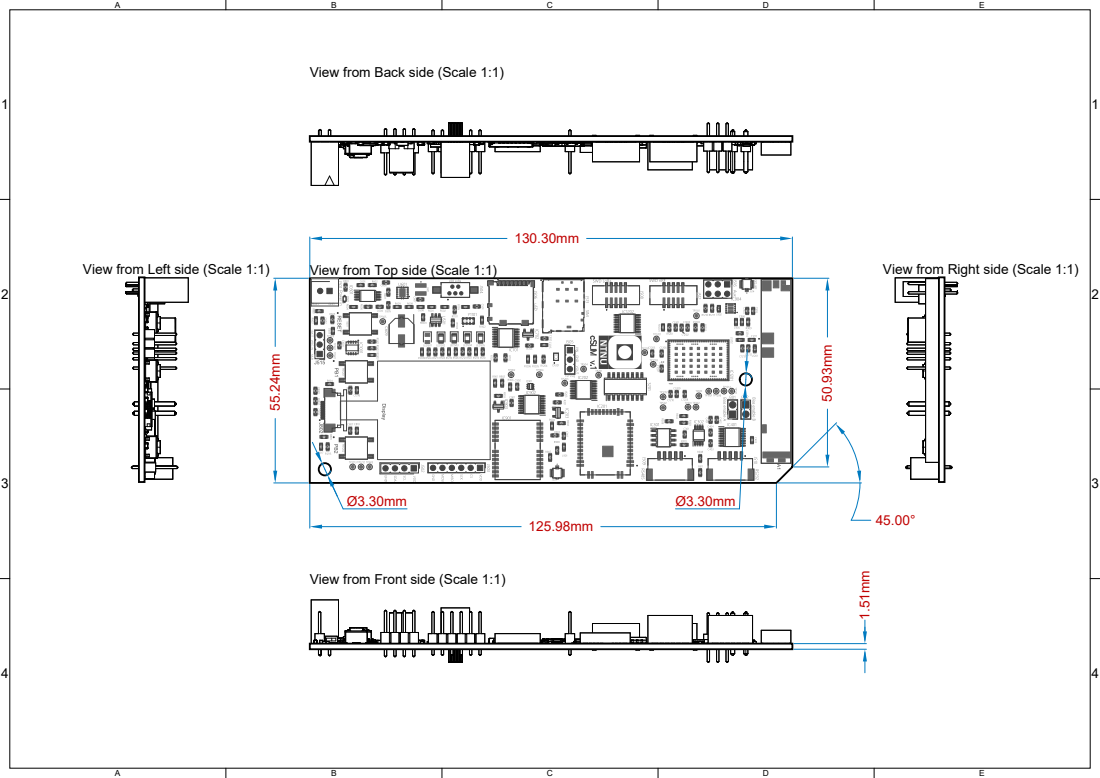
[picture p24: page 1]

View from Back side (Scale 1:1)

View from Top side (Scale 1:1)

View from Front side (Scale 1:1)


View from Top side (Scale 1.1838:1)

View from Front side (Scale 1.2446:1)

View from Bottom side (Scale 1.2258:1)




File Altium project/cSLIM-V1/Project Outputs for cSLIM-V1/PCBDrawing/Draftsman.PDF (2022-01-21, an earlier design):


View from Back side (Scale 1:1)

View from Top side (Scale 1:1)

View from Front side (Scale 1:1)


View from Top side (Scale 1.1838:1)

View from Front side (Scale 1.2446:1)

View from Bottom side (Scale 1.2258:1)




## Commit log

2021-10-12 Added reading materials and notes
2021-10-12 re-added reading material and notes
2021-10-18 Added Altium project files
    [NRF52840-DK.SchLib, SL03-GS08.SchLib, SamacSys_Parts.SchLib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]
2021-10-19 fix lib path to git folder
    [cSLIM-SA.PcbLib, cSLIM-SA.SchLib, cSLIM_connectors.SchDoc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]
2021-10-20 added schematics for nRF9160
    [cSLIM-SA.PcbLib, cSLIM-SA.SchLib, cSLIM-shield-LoRa.SchDoc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]
2021-10-29 Changes in schematic
    [cSLIM-SA.PcbLib, cSLIM-SA.SchLib, cSLIM-shield.SchDoc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]
2021-10-29 Schematics close to finished
    [cSLIM-shield-LoRa.SchDoc, cSLIM-shield.SchDoc, cSLIM_FRAM.SchDoc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]
2021-10-31 Schematics rev1
    [cSLIM-SA-LoRa.SchDoc, cSLIM-SA.PcbLib, cSLIM-SA.SchDoc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]
2021-10-31 schematic PDF
2021-11-01 changes to schematics
    [cSLIM-SA-LoRa.SchDoc, cSLIM-SA.SchDoc, cSLIM-SA.SchLib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]
2021-11-02 Schematic revision
    [cSLIM-SA-LoRa.SchDoc, cSLIM-SA.PcbLib, cSLIM-SA.SchDoc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]
2021-11-03 schematics rev
    [cSLIM-SA-LoRa.SchDoc, cSLIM-SA.SchDoc, cSLIM-SA_FRAM.SchDoc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]
2021-11-03 schematics after design review
    [cSLIM-SA-LoRa.SchDoc, cSLIM-SA.PcbLib, cSLIM-SA.SchDoc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]
2021-11-05 changed footprint source
    [Test_layout.PcbDoc, cSLIM-SA.SchDoc, cSLIM-SA.SchLib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]
2021-11-05 Added components to PCB
    [cSLIM-SA_nRF9160.SchDoc, cSLIM-shield.PrjPcb]
2021-11-09 Routed all nets besides GND
    [cSLIM-SA-LoRa.SchDoc, cSLIM-SA.PcbLib, cSLIM-SA.SchDoc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]
2021-11-10 Completed routing
    [cSLIM-SA-LoRa.SchDoc, cSLIM-SA.PcbLib, cSLIM-SA.SchDoc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]
2021-11-12 fixing top overlay
    [NRF52840-DK.SchLib, SL03-GS08.SchLib, SamacSys_Parts.SchLib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]
2021-11-14 added shield to GPS nRF
    [cSLIM-SA-LoRa.SchDoc, cSLIM-SA.SchDoc, cSLIM-SA_FRAM.SchDoc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]
2021-11-14 clean up
    [Bill of Materials-cSLIM-shield.xlsx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]
2021-11-17 changed TTL circuit for LoRa
    [Bill of Materials-cSLIM-shield.xlsx, NRF52840-DK.SchLib, SL03-GS08.SchLib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]
2021-11-17 ordered PCB
    [cSLIM-SA-LoRa.SchDoc, cSLIM-SA.SchDoc, cSLIM-SA_FRAM.SchDoc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]
2021-11-30 new order
    [Bill of Materials-fixx-version1.xlsx, GANTT_cSLIM_V1_2.xlsx, cSLIM-SA-LoRa.SchDoc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]
2022-01-17 cleaned repo
    [GANTT_cSLIM_V1_2.xlsx, cSLIM-SA-LoRa.SchDoc, cSLIM-SA.SchDoc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]
2022-01-21 fixing schematic library
    [cSLIM-SA-LoRa.SchDoc, cSLIM-SA.SchDoc, cSLIM-SA.SchLib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]
2022-01-22 Edit BOM
    [Bill of Materials-cSLIM_V1.xlsx, cSLIMv1_BOM_extra_materials.xlsx]
2022-06-28 revised master
    [Bill of Materials-cSLIM-shield.xlsx, Bill of Materials-cSLIM_V1.xlsx, Bill of Materials-fixx-version1.xlsx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]
